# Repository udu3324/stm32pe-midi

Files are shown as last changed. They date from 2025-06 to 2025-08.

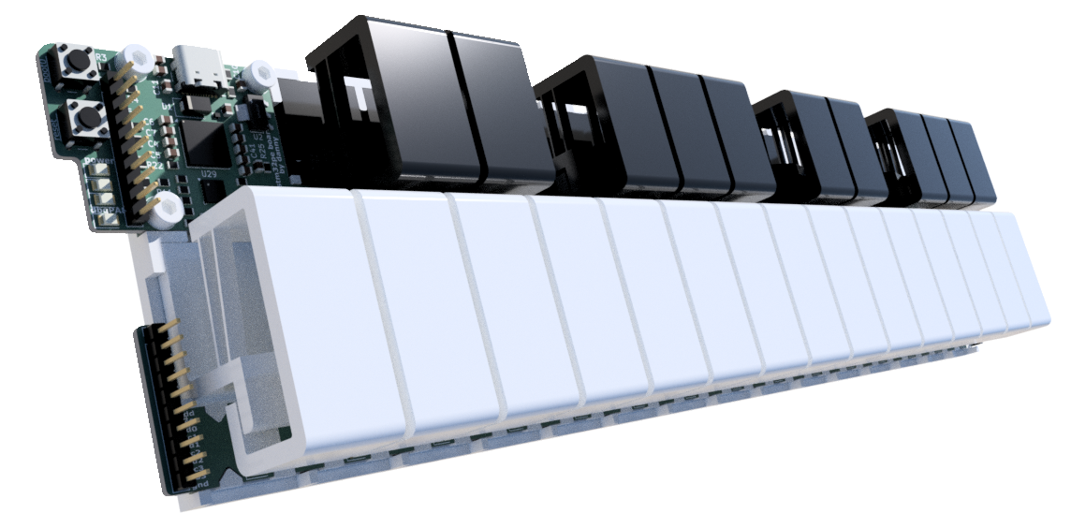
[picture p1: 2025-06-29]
cad/stm32pe-midi case v42 clear.png

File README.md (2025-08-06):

# stm32pe-midi controller



An expressive midi controller based on the stm32 ecosystem. It uses the MPE midi protocol to pass through signals that act as gestures/effects including velocity/note to any music DAW. (like ableton)

 - Uses the powerful STM32H7
 - Uses USB-C OTG to connect to a device
 - Has per key PWM leds for indication
 - Low profile/one sided pcb design
 - Small key footprint for compactness
 - Two octaves + extra key before an octave

See it in action [here](https://www.youtube.com/watch?v=022ZFJn4nkc)!

# Why I Made It

This controller will be able to make music more accessible by being more affordable to the typical person. Most MPE midi controllers on the market cost between [$500 USD to $2000](https://www.expressivee.com/2-osmose). I also made this project to touch the stm32 ecosystem and learn how to integrate and use it. This midi keyboard could also make my workflow nicer for making music in Ableton.



# Design

To reduce the cost of production, I decided to design a compliant mechanism (flexure) that would be only one part. It would reduce the labor and cost by a lot. This is because most keyboards/pianos have between 10 to 100 which I have reduced to a minimum of 2. A hall effect sensor is used to measure the position and rotation of a magnet embedded in each key.



# Problems

There were many problems while prototyping and laying out things. I had bare knowledge of how flexures worked and had to create as many prototypes as needed until the right movement was made. I also didn't know that the size of the board would be a big constraint that was completely ignored.

**I highly recommend to look over these issues before building another stm32pe device!!!**
A lot of tolerances for the 3d prints are based on my 3d-printer. Make sure to print segments before making the entire thing to test for fit between the pcb, magnet, and everything.

Problems during fabrication
 * TMAG5273 has a fixed i2c address which only differs by buying different models (B1, C1, D1) or by running extra interrupt traces
 * M screw spacers broke off when screwing into plastic
 * Too high of a tolerance between the board and 3d printed parts, had to cut off bottom two aligners on all keys
 * Connection (led mux) from main-board to other board was made through really tiny & painful to solder wires

Here's a list of problems after fabrication + firmware
 * The Black key flexure design suffers too much with plastic deformation permanently, as well as temporarily
 * ^ This issue also causes a permanent distance change with less distance to measure and use
 * TMAG5273 library has no calibration feature and the measured angle is offset when brought closer
 * Keys are a bit too slippery and need a dimple to grip the finger
 * Flexures on both key types are a little on the firm side, takes a little time to get used to
 * Last white key (b) is impractical as header wires are blocking its roll to pitch change up
 * The power on led is a bit too bright, not changeable
 * The base/case of the stm32h7 is kinda slippery
 * PLA flexures can get deformed under heat in a car which can leave a permanent loss of height on keys or mess more with the already high tolerance to allow press fitting

These issues do not make the stm32pe midi keyboard worthless or horrible to use, but are just little tiny problems that could be polished in the future.

# Firmware

 * [tinyusb lib](https://github.com/hathach/tinyusb) on MIT license
 * [i2c-mux stm32 lib](https://github.com/jtainer/i2c-mux) on BSD-2-Clause license
 * [stm32 tmag5273 lib](https://github.com/devOramaMan/stm32_TMAG5273) on No license (added a i2c address rewrite based on the datasheet as well as a crucial fix)

Thank you to all the open source libraries above to make this project possible. I don't think I would have the expertise to implement all my ics this well.

The firmware for the stm32pe midi controller is written in c/cpp on stm32cubeide and flashed with stm32cubeprogrammer. Amazing platform. Outdated UI (lol). **To be as transparent as possible**, some of the firmware was written/assisted with AI. About 20% of it was written mostly with AI, while the rest + logic that ties everything together was me. `mpe.c`, 80% of `helper.c`, 60% of `tlc5940.c`, and 5% of `main.c` with some fixes to `TMAG5273.c` was assisted with AI. I do understand what the firmware does. Depending on your perspective on AI, it shouldn't really matter as I know what I'm doing. 

All of the code is stored in `firmware/stm32pe_midi/Core/Src` or `/Core/Inc`. `Src/main.c` contains some user preferences that can be set through variables.

```c
//midi
int start_octave = 4; //midi code shift
int mt_send_black = 40; //midi on threshold
int mt_send_white = 30; //midi on threshold

//mpe
int16_t pitch_mpe_st = 682; //mpe semitone pitch range (682 = 4st, 341 = 2st)
float angle_mpe_padding = 15; //mpe pitch
float angle_mpe_realistic_max = 25; //mpe pitch

float aftertouch_mpe_white_padding = 9; //mpe aftertouch
float aftertouch_mpe_black_padding = 15; //mpe aftertouch

//octave
uint32_t octave_change_mode_time_threshold = 200; //diff change between mode/octive
uint32_t octave_led_flash = 500; //ms between led flash during mode

//led
int startup_cutoff_wait = 100; //led cutoff + cutoff for initial sensor readings saving

//mode
uint32_t octave_mode_hold_down = 1500; //octave mode keys milliseconds to hold down & change
uint32_t mpe_mode_hold_down = 3000; //~ same above but for mpe mode keys

//debug
bool disable_comport = false; //silences comport to possibly make processing faster?
```

# Wiring





# BOM
This is an approximate bill of materials that is a little flexible. It would be around $333.27, ±5 dollars in case of shipping or extra taxes/fees. Thank you Hack Club - Highway for funding this.

| Part | Cost | Count | Supplier | Note | Link |
|---|---|---|---|---|---|
| PLA Filament (white) | $16.99 | 1 | Amazon | I have a 3d printer and would like to print most of the parts. | [https://www.amazon.com/dp/B07PGZNM34](https://www.amazon.com/dp/B07PGZNM34) |
| PLA Filament (black) | $16.99 | 1 | Amazon | ~ (for the black keys) | [https://www.amazon.com/dp/B07PGY2JP1](https://www.amazon.com/dp/B07PGY2JP1) |
| UV Plastic Glue | $14.15 | 1 | Amazon | This is for the underside of the keys to stop scraping. | [https://www.amazon.com/dp/B00QU5M4VW](https://www.amazon.com/dp/B00QU5M4VW) |
| Header 10 Pins | $0.78 | 2 | DigiKey  | (does not include shipping/taxes) | [68000-110HLF](https://www.digikey.com/en/products/detail/amphenol-cs-fci/68000-110HLF/1878503) |
| Header 5 Pins | $0.63 | 1 | DigiKey  | ~ | [68000-105HLF](https://www.digikey.com/en/products/detail/amphenol-cs-fci/68000-105HLF/2023304) |
| PCB Fabrication + Assembly | $151.09 | 2 | JLCPCB | *no coupons applied yet | |
| PCB Shipping | $33.52 | n/a | ~ | | |
| Customs duties & taxes | $83.10 | n/a | ~ | | |
| Sales Tax | $15.24 | n/a | ~ | | |
| TOTAL | $333.27 | | | | |

I forgot to add two more parts to the bom. They have been covered out of pocket which is fine

| Part | Cost | Count | Supplier | Note | Link |
|---|---|---|---|---|---|
| 5mm Cube Magnets | $16.99  | 45 | Amazon | I could not find any listings with lower quantities | [https://www.amazon.com/dp/B0CW9GVTX2](https://www.amazon.com/dp/B0CW9GVTX2) |
| M3 5mm Screws | ¥2.14 | 50 | Taobao | Pretty cheap! (30 cents usd) | [https://detail.tmall.com/item.htm?id=722759297726](https://detail.tmall.com/item.htm?id=722759297726) |
| Female 10pin Headers  | $5.62 | 1 | Mouser | This is for the main board. The part itself **costs $0.63 without taxes/shipping.** | [https://www.mouser.com/ProductDetail/710-61301011821](https://www.mouser.com/ProductDetail/710-61301011821) |
| JLCPCB Two Design Fee | $38.99  | n/a | JLCPCB | 😭 i did not think about this while designing, i tried negotiating and doing everything | |
| TMAG5273-B1/C1/D1 | $23.28  | 18 | Mouser | i stg the datasheet said the sensor's i2c addresses were reprogrammable.. but they didn't say i needed to hookup interrupts to them too... lesson learned :p | |
| Total out of pocket | $85.18  | | | | |
| REAL TOTAL | $418.45 | | | | |

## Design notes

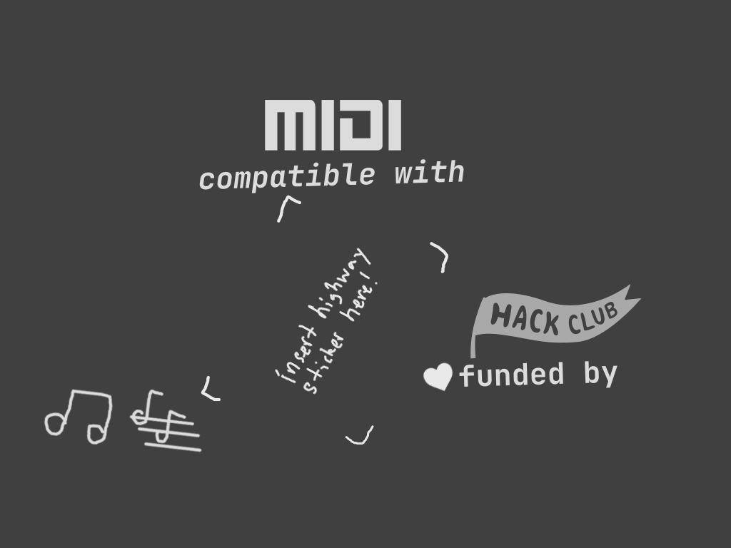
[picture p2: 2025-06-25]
pcb/stm32pe_midi/main_board_v2_graphic.png

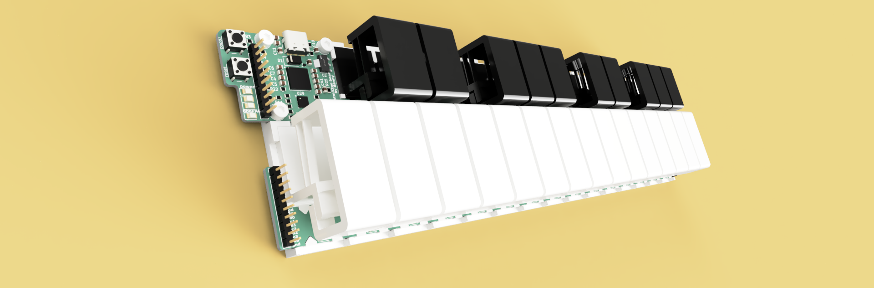
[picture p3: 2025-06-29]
cad/stm32pe-midi_case_2025-Jun-29_01-04-10AM-000_CustomizedView29163511781_png.png

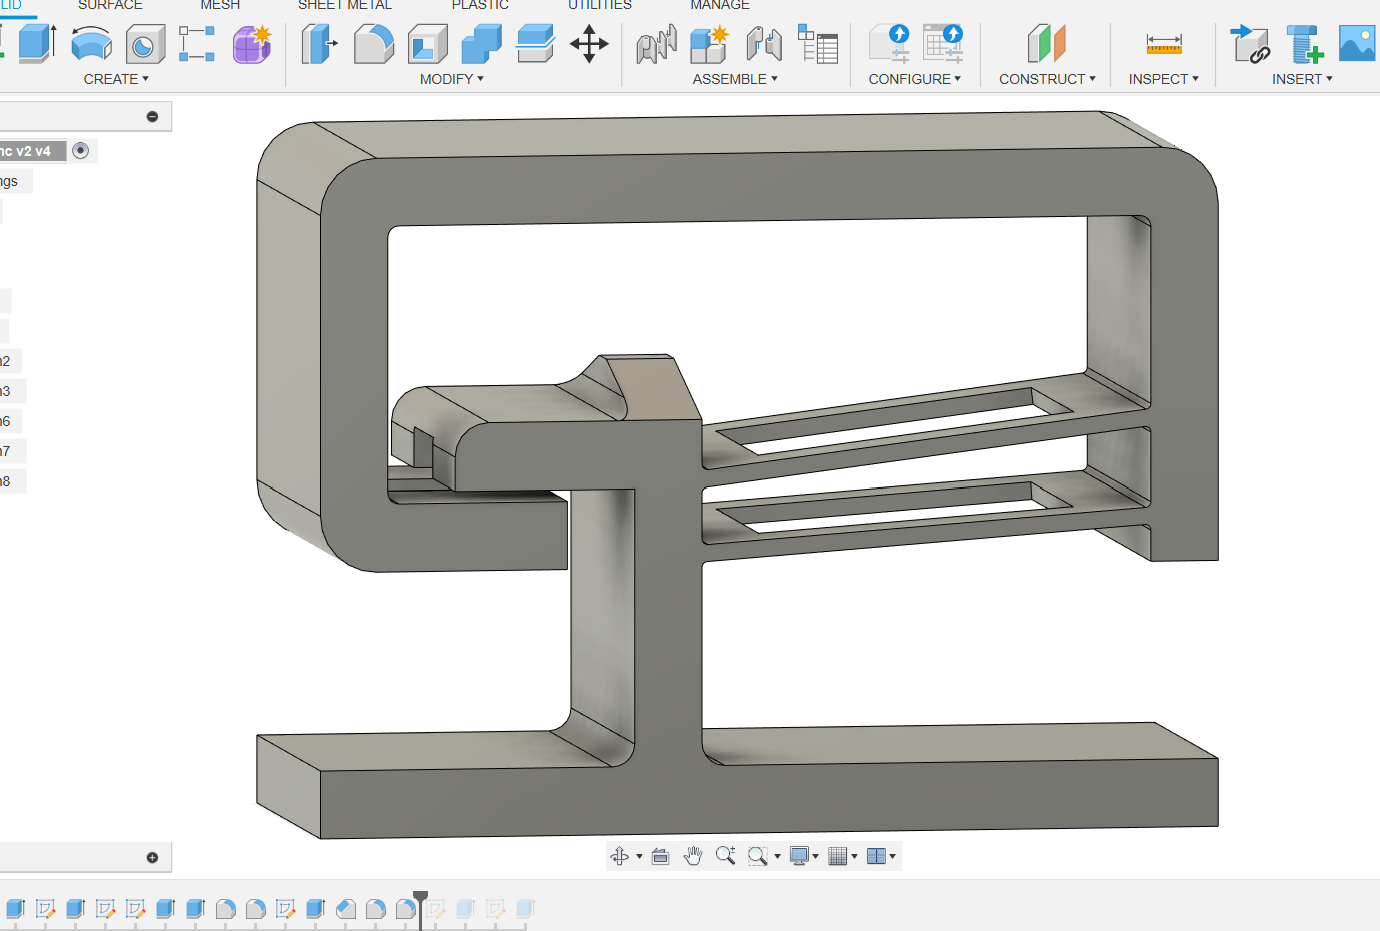
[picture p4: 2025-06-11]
cad/key/v2.png

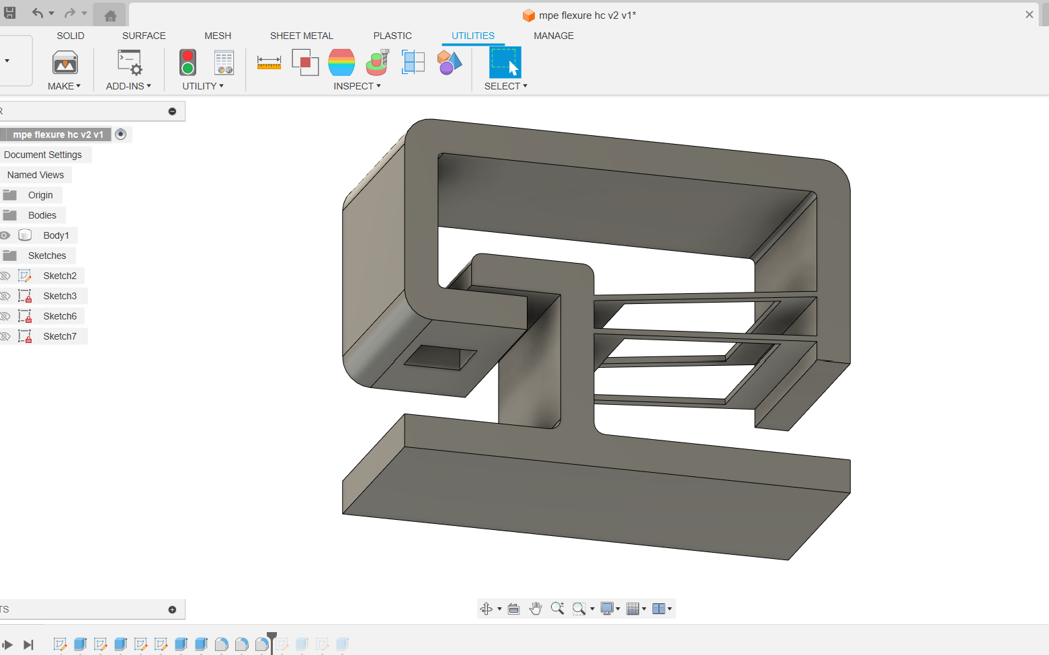
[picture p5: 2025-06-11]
cad/key/v1.png

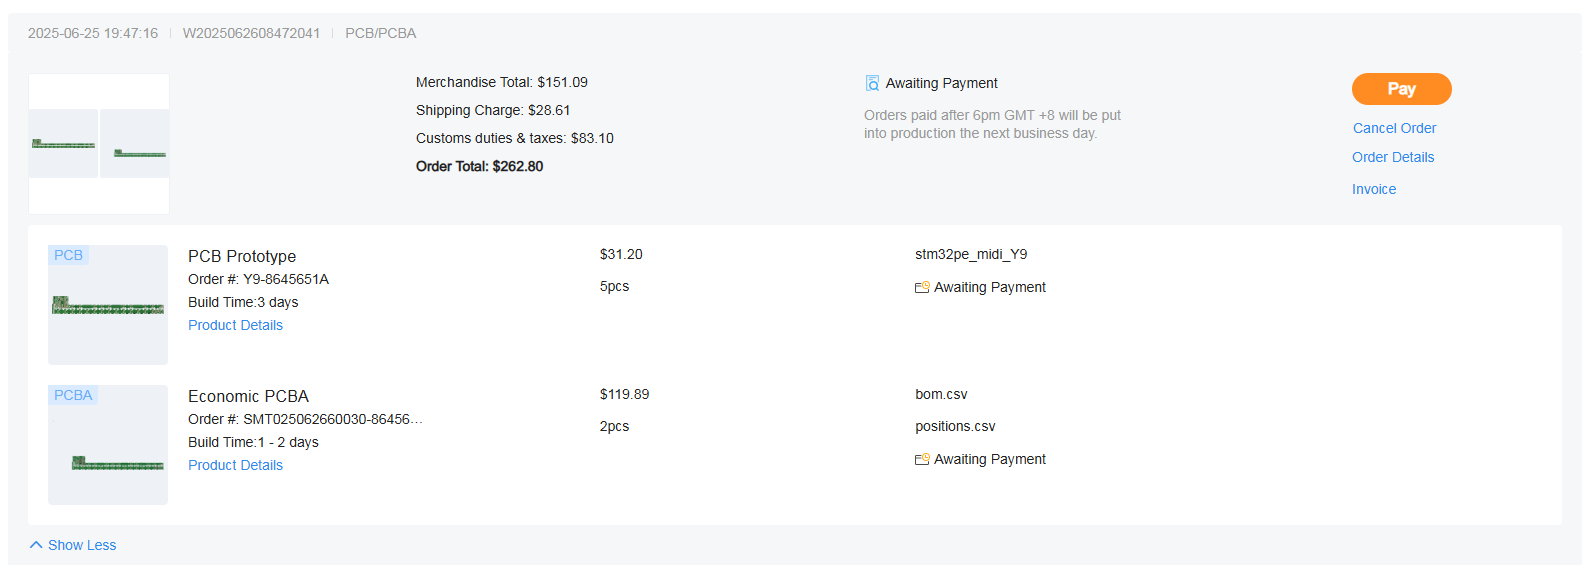
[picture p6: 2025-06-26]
production/jlcpcb info/cart.png

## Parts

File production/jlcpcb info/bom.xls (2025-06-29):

Comment | Designator | Footprint | JLCPCB Part #
LED_Small | D3,D33,D4,D5,D10,D11,D12,D13,D14,D15,D16,D17,D18,D19,D20,D21,D22,D23,D24,D25,D26,D27,D28,D29,D30,D6,D7,D8,D9 | 1206 | C3646938
SS14 | D1 | D_SMA | C2480
1μF | C13,C14,C8 | 0805 | C28323
LM3940IMPX-3.3/NOPB | U2 | SOT-223-4_L6.5-W3.5-P2.30-LS7.0-BR | C544820
4.7μF | C3,C5 | 0805 | C1779
2.2μF | C1,C2 | 0805 | C377773
100nF | C15,C16,C17,C18,C19,C20,C21,C22,C23,C24,C25,C26,C27,C28,C29,C30,C31,C32,C33,C34,C35,C36,C37,C38,C39,C40,C41,C12,C4,C6,C7,C9 | 0805 | C49678
TLC5940PWP | U30,U31 | HTSSOP-28-1EP_4.4x9.7mm_P0.65mm_EP3.4x9.5mm_Mask2.4x6.17mm_ThermalVias | C181653
0.47μF | C11 | 0805 | C13967
2.2kΩ | R10,R11,R12,R13,R14,R15,R16,R17,R18,R19,R20,R21,R22,R23,R8,R9 | 0805 | C17520
TMAG5273 | U10,U11,U12,U13,U14,U15,U16,U17,U18,U19,U20,U21,U22,U23,U24,U25,U26,U27,U3,U4,U5,U6,U7,U8,U9 | SOT-23-6_L2.9-W1.6-P0.95-LS2.8-BR | C3716049
10kΩ | R3,R4 | 0805 | C17414
330Ω | R27,R5,R6,R7 | 0805 | C17630
TPD2EUSB30 | U28 | Texas_DRT-3 | C2844720
33μF | C10 | 0805 | C342635
STM32H743VIHx | U1 | TFBGA-100_8x8mm_Layout10x10_P0.8mm | C964146
5.1kΩ | R1,R2,R24,R25 | 0805 | C27834
TCA9548A | U29 | Texas_RGE0024C_VQFN-24-1EP_4x4mm_P0.5mm_EP2.1x2.1mm | C555456
USB4105 | J1 | USB_C_Receptacle_GCT_USB4105-xx-A_16P_TopMnt_Horizontal | C3025063

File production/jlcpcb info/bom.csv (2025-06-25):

Designator | Footprint | Quantity | Value | LCSC Part #
C1, C2 | 0805 | 2 | 2.2μF
C10 | 0805 | 1 | 33μF
C11 | 0805 | 1 | 0.47μF
C12, C4, C6, C7, C9 | 0805 | 5 | 100nF
C13, C14, C8 | 0805 | 3 | 1μF
C15, C16, C17, C18, C19, C20, C21, C22, C23, C24, C25, C26, C27, C28, C29, C30, C31, C32, C33, C34, C35, C36, C37, C38, C39, C40, C41 | 0805 | 27 | 0.1μF
C3, C5 | 0805 | 2 | 4.7μF
D1 | D_SMA | 1 | SS14
D10, D11, D12, D13, D14, D15, D16, D17, D18, D19, D20, D21, D22, D23, D24, D25, D26, D27, D28, D29, D30, D6, D7, D8, D9 | 1206 | 25 | LED_Small
D3, D33, D4, D5 | 1206 | 4 | LED
J1 | USB_C_Receptacle_GCT_USB4105-xx-A_16P_TopMnt_Horizontal | 1 | USB4105
J3 | PinHeader_1x05_P2.54mm_Vertical | 1 | Conn_01x05_Pin
J4 | PinHeader_1x10_P2.54mm_Vertical | 1 | Conn_01x10_Pin
J5 | PinHeader_1x10_P2.54mm_Vertical | 1 | Conn_01x10_Socket
J6 | custom_pads | 1 | Conn_01x05_Pin
MOUSE-BITE-2MM-SLOT-1, MOUSE-BITE-2MM-SLOT-2, MOUSE-BITE-2MM-SLOT-3, MOUSE-BITE-2MM-SLOT-4, MOUSE-BITE-2MM-SLOT-5 | mouse-bite-2mm-slot | 5 | VAL**
R1, R2, R24, R25 | 0805 | 4 | 5.1kΩ
R10, R11, R12, R13, R14, R15, R16, R17, R18, R19, R20, R21, R22, R23, R8, R9 | 0805 | 16 | 2.2kΩ
R27, R5, R6, R7 | 0805 | 4 | 330Ω
R3, R4 | 0805 | 2 | 10kΩ
SW1, SW2 | SW_PUSH_6mm | 2 | SW_SPST
U1 | TFBGA-100_8x8mm_Layout10x10_P0.8mm | 1 | STM32H743VIHx
U10, U11, U12, U13, U14, U15, U16, U17, U18, U19, U20, U21, U22, U23, U24, U25, U26, U27, U3, U4, U5, U6, U7, U8, U9 | SOT-23-6_L2.9-W1.6-P0.95-LS2.8-BR | 25 | TMAG5273 | C3716049
U2 | SOT-223-4_L6.5-W3.5-P2.30-LS7.0-BR | 1 | LM3940IMPX-3.3/NOPB | C544820
U28 | Texas_DRT-3 | 1 | TPD2EUSB30
U29 | Texas_RGE0024C_VQFN-24-1EP_4x4mm_P0.5mm_EP2.1x2.1mm | 1 | TCA9548A
U30, U31 | HTSSOP-28-1EP_4.4x9.7mm_P0.65mm_EP3.4x9.5mm_Mask2.4x6.17mm_ThermalVias | 2 | TLC5940PWP

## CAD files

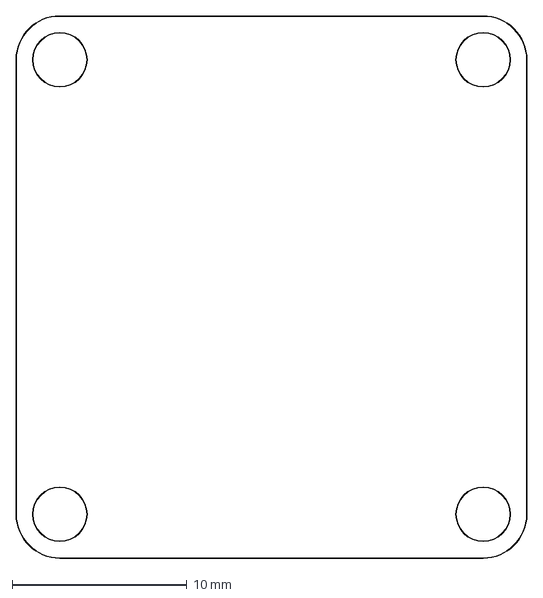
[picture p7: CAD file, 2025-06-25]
pcb/stm32pe_midi/main_board.dxf
29.2 x 31.0 mm

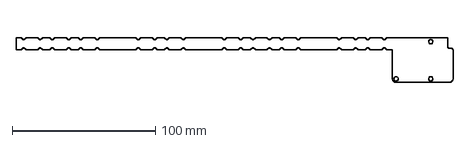
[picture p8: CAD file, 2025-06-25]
pcb/stm32pe_midi/main_board_v2.dxf
304.7 x 31.4 mm

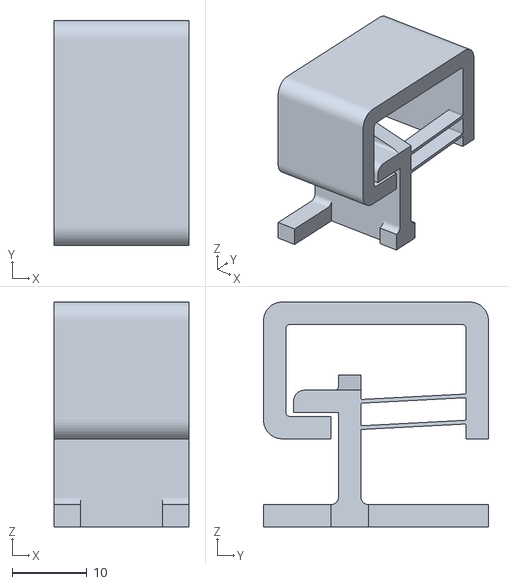
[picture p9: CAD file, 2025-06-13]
cad/small key/14.stl
18.0 x 30.0 x 30.0

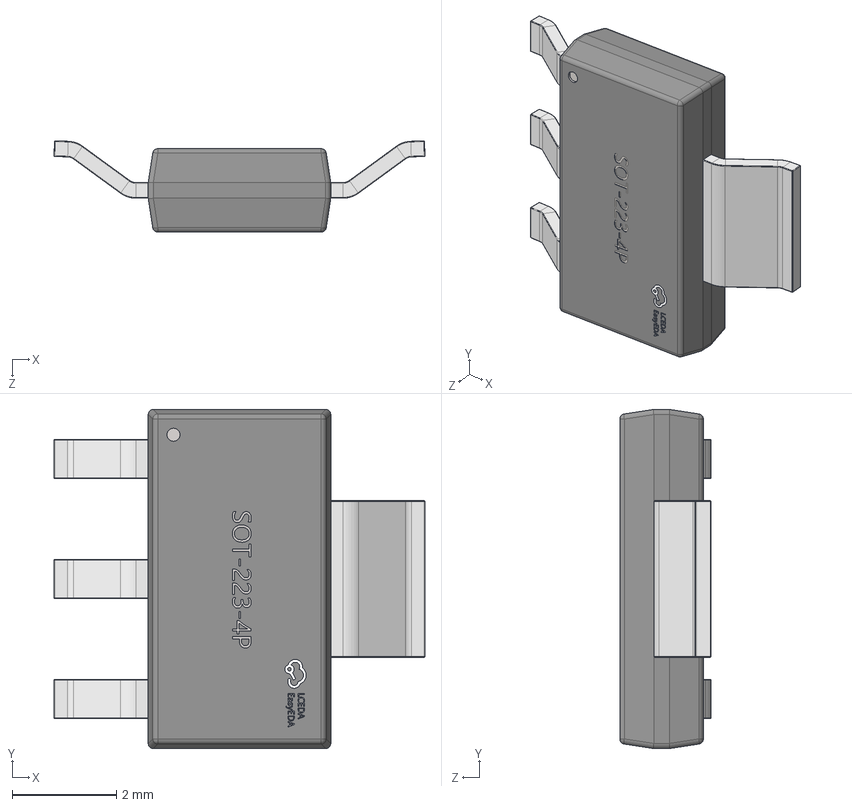
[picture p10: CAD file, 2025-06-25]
pcb/stm32pe_midi/SOT-223-4P_L6.5-W3.5-H1.6-LS7.0-P2.30.step
7.11 x 6.50 x 1.75 mm

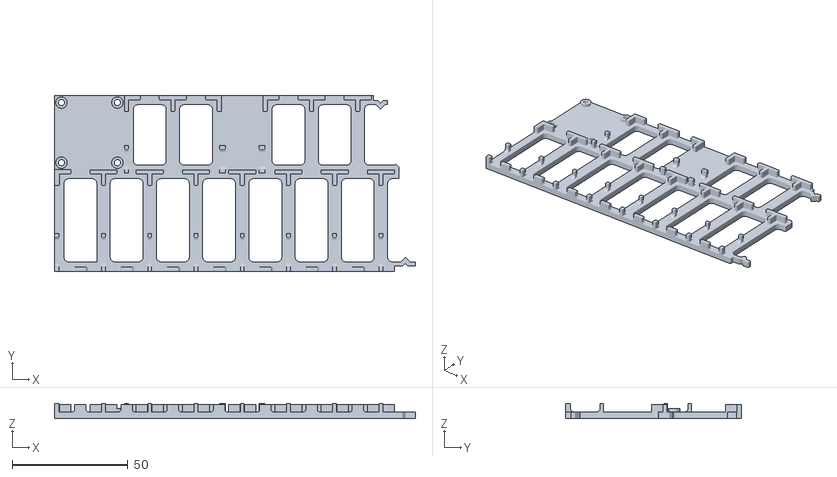
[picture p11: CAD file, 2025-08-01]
production/Case L.stl
156.1 x 76.0 x 6.50

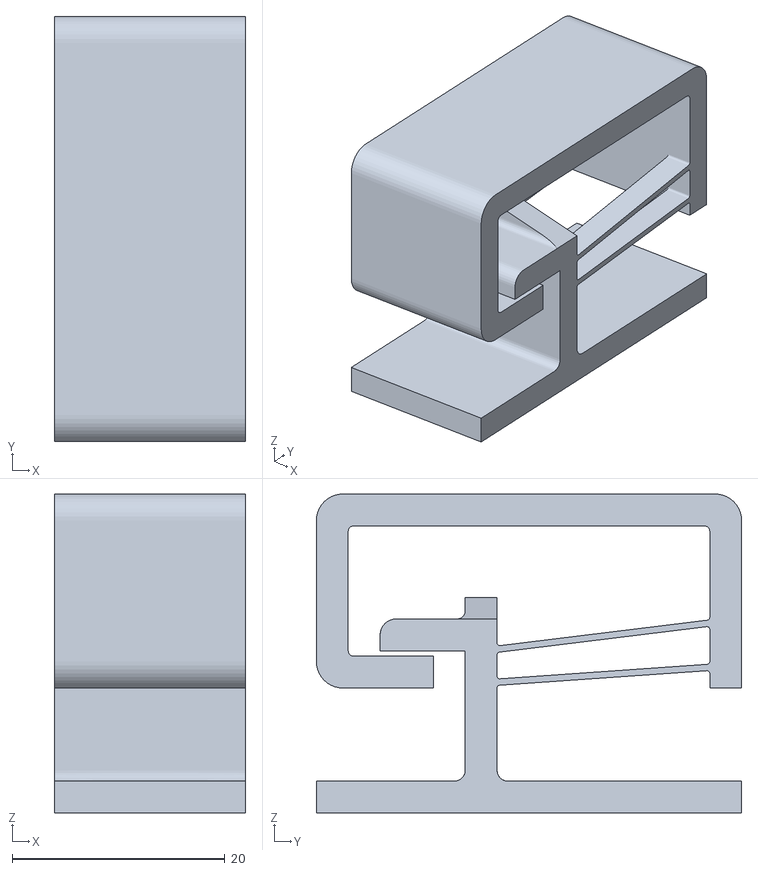
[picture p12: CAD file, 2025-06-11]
cad/key/v3.stl
18.0 x 40.0 x 30.0

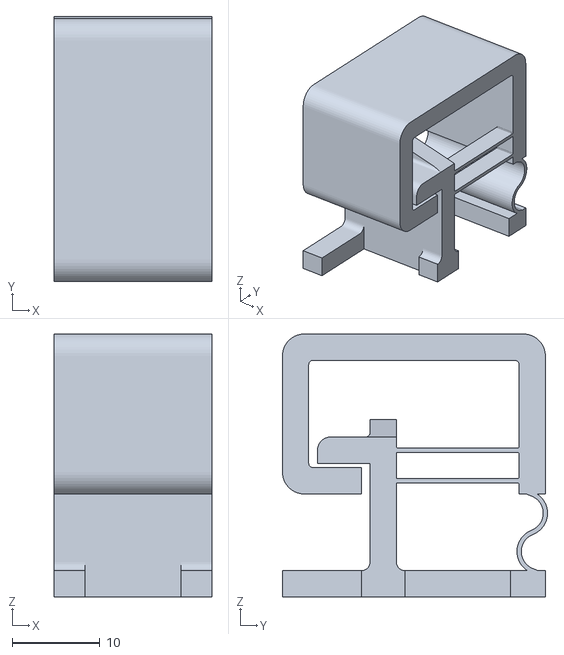
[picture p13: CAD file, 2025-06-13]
cad/small key/15.stl
18.0 x 30.2 x 30.0

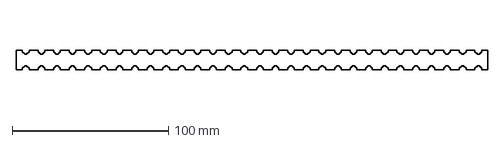
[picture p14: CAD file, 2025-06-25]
pcb/stm32pe_midi/sensor_line_1.dxf
302.0 x 12.7 mm

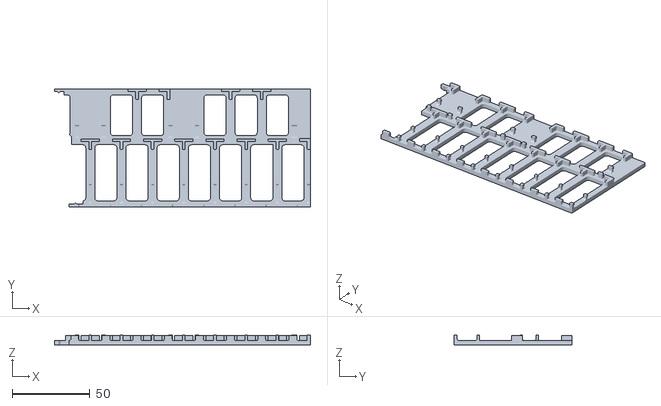
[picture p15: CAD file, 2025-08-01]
production/Case R.stl
164.2 x 76.0 x 6.50

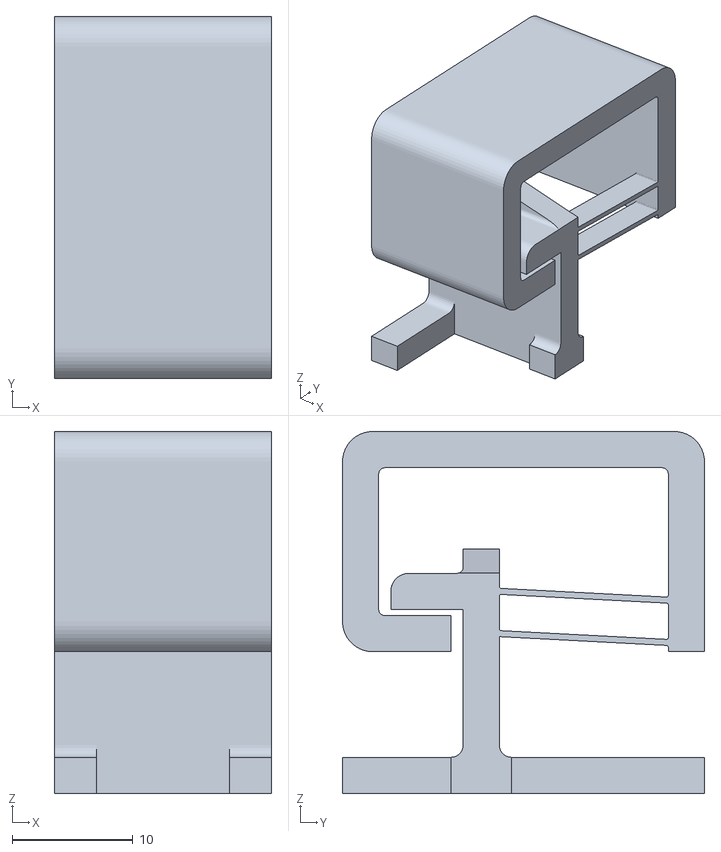
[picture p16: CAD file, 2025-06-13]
cad/small key/v11.stl
18.0 x 30.0 x 30.0

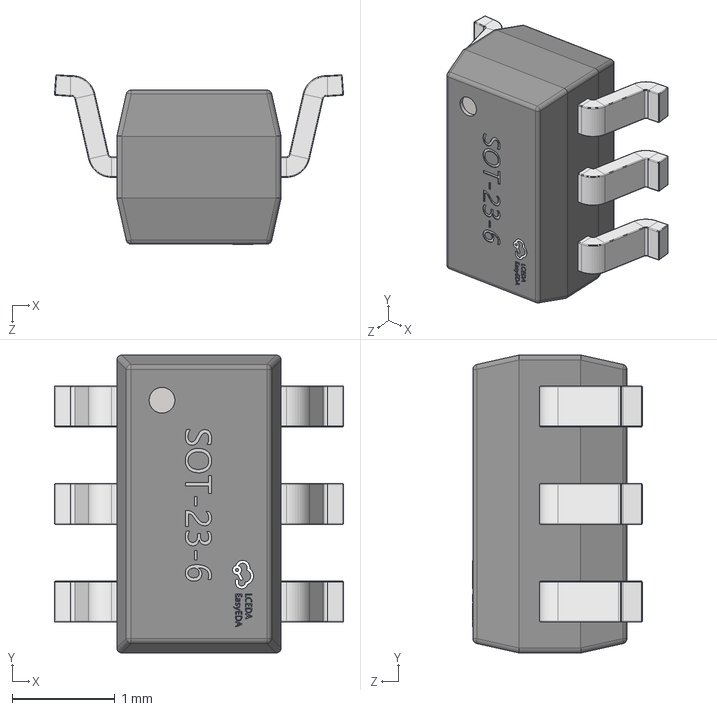
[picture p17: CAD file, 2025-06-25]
pcb/stm32pe_midi/SOT-23-6_L2.9-W1.6-H1.5-LS2.8-P0.95.step
2.81 x 2.90 x 1.65 mm

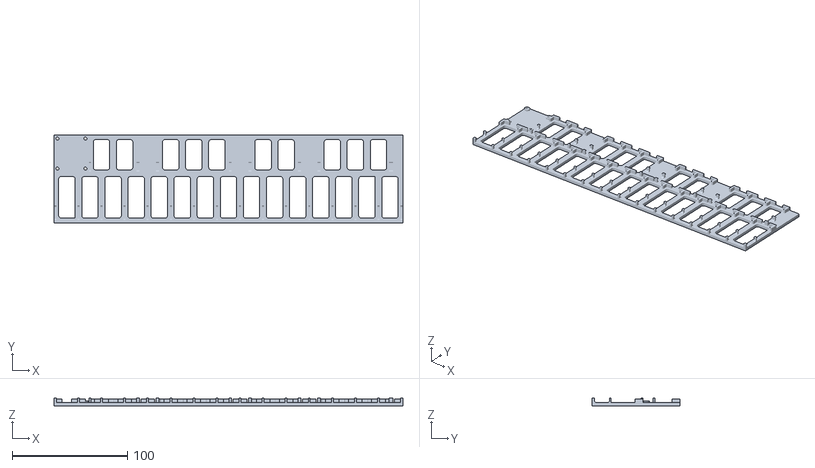
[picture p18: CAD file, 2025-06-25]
production/case.stl
302.5 x 76.0 x 6.50

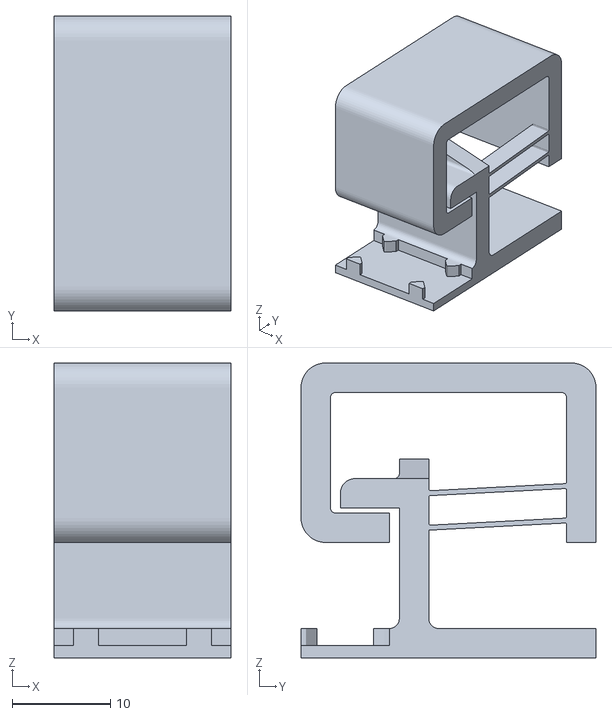
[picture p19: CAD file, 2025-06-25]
production/mpe flexure small.stl
18.0 x 30.0 x 30.0

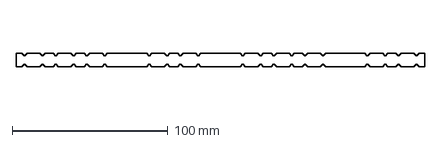
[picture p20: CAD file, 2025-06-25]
pcb/stm32pe_midi/sensor_line_2.dxf
262.0 x 8.70 mm

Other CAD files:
production/hc_flexure_key_magdim_good.stl
cad/small key/13.stl
production/mpe flexure.stl
cad/small key/12.stl
cad/key/v1.f3d
cad/key/v1.stl
cad/key/v2.f3d
cad/key/v2.stl
cad/key/v3.f3d
cad/small key/16.stl
cad/small key/smal ver v1.stl
cad/small key/small ver v1.f3d
cad/small key/small ver v2 final prototype v2.f3d
cad/small key/small ver v2 v16.f3d
cad/small key/small ver v2.f3d
cad/small key/small ver v2.stl
cad/small key/small ver v3.f3d
cad/small key/small ver v3.stl
cad/small key/v10.stl
cad/small key/v9.stl
pcb/stm32pe_midi/sensor_line_v2.dxf

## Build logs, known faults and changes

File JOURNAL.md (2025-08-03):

---
title: "stm32pe midi controller"
author: "@Danny"
description: "An affordable music keyboard that enables more expression through the MIDI Polyphonic Expression (MPE) protocol."
created_at: "2025-06-06"
---

**Total time taken: 52 hours**

**Total time taken: 131.5 hours (fabrication + firmware)**

# June 6th: Sketching out the idea

Today, I started researching the components that I would depend on. (stm32 ecosystem, i2c multiplexers, sensors) I then created some technical sketches of the device and drew some core concepts. 

Feature Set
 - Recognizable by Ableton (or any general DAW software)
 - Sends mpe midi (duh)
 - USB-C connection for flashing & otg device
 - (optional) 3.5mm jack for int. synth engine
 - Cool rgb indicators



Components Needed
 - **STM32H7**43VIH (great mcu, bga style needing multilayer pcb fab)
 - TMAG5273 - I2C hall effect sensor
 - TCA9548A - For multiplexing i2c connections
 - Possibly SDRAM for an internal synth engine
 - IO Ports, Encoder
 - other smd components

**Total time spent: ~3 hours**

# June 8th: Getting the TMAG5273 to work

The core idea of this controller was to use a hall effect sensor (tmag5273) to measure the position of a magnet and output many things out of it. Before continuing any further, I need to make sure that it works.

## Wiring

Two resources were used in wiring the sensor. I looked at the [datasheet](https://www.ti.com/lit/ds/symlink/tmag5273.pdf) first to get an idea of the pinout and reference circuit, as well as how sparkfun implemented it through their board [here](https://docs.sparkfun.com/SparkFun_Qwiic_Hall_Effect_Sensor_TMAG5273/assets/board_files/schematic-mini.pdf). 

I decided for now to use my [esp32 devkit](https://docs.espressif.com/projects/esp-dev-kits/en/latest/esp32s3/esp32-s3-devkitc-1) to test out the sensor before switching to the stm32 ecosystem.

The INT pin for disabling the sensor was left unconnected, SDA and SCL to any GPIO with a 4.7k pullup resistor, and VCC to 3.3V. 



## Code

I am using PlatformIO's VSC plugin to flash and test everything. The first thing to flash was a simple [I2C device scanner](https://randomnerdtutorials.com/esp32-i2c-communication-arduino-ide) to see if I had everything wired correctly. This process took quite long as I did not know if the sensor was fried or if my wiring was horrible. (it was both 😭)

I can then move onto [sparkfun's library](https://github.com/sparkfun/SparkFun_TMAG5273_Arduino_Library) to communicate with the tmag sensor.

```cpp
#include <Arduino.h>
#include <Wire.h>
#include "SparkFun_TMAG5273_Arduino_Library.h" 

TMAG5273 sensor;

uint8_t i2cAddress = 0x35;

const int ledPin = 17;  // GPIO 17
const int I2C_SDA = 4;
const int I2C_SCL = 5;

void setup() {
  Serial.begin(115200);
  delay(1000);
  pinMode(ledPin, OUTPUT);  // Set GPIO 17 as an output
  Wire.begin(I2C_SDA, I2C_SCL);

  Serial.println("hello world");

  // If begin is successful (0), then start example
  if (sensor.begin(i2cAddress, Wire) == 1) {
    Serial.println("Begin");
  } else {
    Serial.println("Device failed to setup - Freezing code.");
  }
}

void loop() {
  // Checks if mag channels are on - turns on in setup
  if (sensor.getMagneticChannel() != 0) {
    sensor.setTemperatureEn(true);

    float magX = sensor.getXData();
    float magY = sensor.getYData();
    float magZ = sensor.getZData();
    float temp = sensor.getTemp();

    //Serial.printf("( %7.2f, %7.2f, %7.2f ) mT   %6.2f C\n", magX, magY, magZ, temp);
    
    Serial.printf("%f,%f,%f,%f\n", magX, magY, magZ, temp);
    //relative to dot on ic facing forward to viewer
    // left-right, forward-backward, up-down
  } else {
    Serial.println("Mag Channels disabled, stopping..");
  }

  delay(50);
}
```



**Total time spent: 3.5 hours**

# June 9th: Designing the flexures for the keys

I started off on a new page and drew two concepts of how I could implement [flexures](https://web.mit.edu/mact/www/Blog/Flexures/FlexureIndex.html) in a key. It would allow me to build the device with less parts with the same functionality, as well as saving on money. The print layers also had to be thought of to make sure flexing won't compromise on durability and break. 

Below is some rough sketches of how the keys would look like and how it would come together with the pcb. 



**Total time spent: 2 hours**

# June 10th: Cadding and 3d printing key prototypes

I decided that I'll choose the more simpler key with only one model that i need to create. I am using Fusion 360 to accomplish this with their personal plan.

Key Requirements (ahaha get it)
 - Fits a 5mm cube neodymium magnet
 - Flexes easily, doesn't strain fingers
 - Can flex in all the neccesary axis
 - Use little to no extra plastic when printing

## Prototype V1

v1

This was the first prototype to kickstart my idea of a key. I started off with a side sketch and extruded it, then adding features in the other dimension. 



Well.. It did not turn out great the first try, and of course it would never be perfect the first try. I designed the flexure to be too thin and it wouldn't hold up the upper weight of the key. It also could not fit the magnet.

Instead of it flexing left or right, the key decided to rotate in place which i did not intend to. But wait... This gave me a new **game breaking** idea! Instead of+ designing it to move in two axises, I can just have it move in one axis and rotate in place which can also be measured by the sensor! It is something so unique that I could have never thought of without this prototype. 

## Protype V2

v2

This second prototype solved many problems of the first one. It finally held the magnet, its own weight, and almost has the rotation action perfect.



The only two problems now is that it is a bit stiff for a key on a midi keyboard as well as something I didn't think about for fabrication. Pressing it all the way down while trying to rotate it scrapes the layer lines making an irritating noise. 

## Prototype V3

v3

This prototype solved the issue of the key being too stiff. It requires less force to push down now, but still has the scraping problem which I'm not sure how to solve. I'll do that later lol.



The data isn't as smooth as i hoped, but I think thats an issue in the code. The white line looking like a sine wave is the rotation movement of the key.

**Total time spent: 5 hours** (2 hrs of printing)

# June 11-13th: Prototyping the smaller keys

I decided that there would be a smaller version of a key for the sharps and flats on the controller. It seemed easy at first until changing the length of a key would mean tweaking every other aspect of the flexure endlessly.



A total of 13 prototypes were printed. Many problems were faced, including but not limited to.... low durability, permanent deformation, too much pressure to push down, no springines, and my lack of knowledge in making flexures. Although I chose aesthetics over functionality, I think everything will turn out great. 

**Total time spent: 2.5 hours** (accumulated, not including hours of printing)

# June 16th: Creating board schematics

I started working on the schematics for the board to bring all the components I need together.



So far, I have been following the [power supply scheme](https://www.st.com/resource/en/datasheet/stm32h743vi.pdf) from the stm32 datasheet as well as researching some other sources. I chose KiCad to build my board in as it is free and an amazing open source tool. 

I still need to add some sort of fuse to the VBUS of the usb-c to protect against esd, as well as my sensors, leds, possibly a dac with audio out, and most definitely a button to allow flashing firmware to the mcu. 

**Total time spent: 3 hours**

# June 17th: Adding the rest

The boot and reset button needed to flash firmware was added as well as some useful indicator LEDs.



I decided to create a sub-sheet to fit all my sensors on another page. 



**Total time spent: 3 hours**

# June 18th: Working on cad assembly

I decided that I would bring everything together to then model the size of the pcb to then take into KiCad. Currently, I am only familiar with OnShape's assembly feature and have no clue how it will go. 



It went horrible of course. I tried editing my sub-assemblies to add a pcb groove but kept on running into so many issues. It took many sketches and saving/syncing issues until I finally was able to modify parts across f3d projects without f**king everything up. 



I made sure to include a 0.15mm gap which would hopefully allow some tolerance for the pcb to fit. (±0.2mm for shape, ±10% for thickness) It would also create a friction fit for the board as well.

**Total time spent: 4 hours**

# June 20th: Adding leds + more



I had to multiplex my leds to use less io on the stm32. The TLC5940 seemed like the best fit for me as it was pwm and would be nice if each key would have some sort of power indicator. 

I also used KiCad's feature of assigning every symbol to a footprint. I decided on every capacitor and resistor having the same package size (0805/2012 metric) and it being not microscopic in case of any repairs and to simplify the bom.



I decided to add a way to output audio. It uses a MCP4922 and two LM396s to allow simple, not audiophile quality, audio delivery to the user.



I was able to test a more simplified/mono design of the audio circuit some time ago with the parts I got from high seas.

**Total time spent: 2 hours**

# June 22th: Cadding plate + pcb layout



I finished up the plate/thing that would hold everything together. So far, most things are press fit into place while the main board uses m3 screws.



I had no clue what i was getting myself into. Everything is laid out with the proper resistors or capacitors next to each other, but its a super dense board which creates a whole list of other challenges.

It was a pain trying to get everything to fit in the first place. I had to remove two extra leds, remove the entire audio output circuit (rip..), redo some schematics, and contemplate my life choices. 



All that's needed left is to route all the traces and place the pullup resistors for the sda/scl lines, as well as calculating the amount of headers i need for the wires between the three boards.

**Total time spent: 7 hours**

# June 23th + 24th: Unseen Constraints - Routing All Traces



I should have thought of the size of my board before doing anything. That was my hugest mistake. I was constrainted to the size/shape of my board which I never thought of while cadding only until now after some work was done.

I had to...

 - remove some features
 - resize the board to fit some components
 - constantly mess around with previous traces (because past me did not think about the future)
 - edit the heat spreader of the led multiplexer to be smaller which is kinda sus but who cares lol
 - cope



In the end, I managed to get everything wired up. KiCad still yells about certain things being unconnected as well as a list of other stuff that isnt really important. I'm really proud of the work as this is a new high for me.



While 80% done tracing everything, I decided to export the pcb to jlcpcb to see how much it would cost so far. It was priced around ~$140 USD for assembling two boards. I then clicked checkout and... I forgot there was tariffs going on right now.. (totaling around $230)

**Total time spent: ~14 hours**

# June 25th: Final touches + more

kicad_t1TWV0PZLa

After routing everything, I made sure i had no critical errors by using KiCad's design rule checker (DRC for short). It revealed a ton of problems like unconnected grounds, traces, and more. Although some components were marked as too close to others, it was only by a little and i could safely ignore it.





I have no clue how i didn't notice this at all. I placed my sensor in the wrong place and only found out last second. It wasn't a pain to move though.



Here's the actual final final look of the pcb. It is amazing.

**Total time spent: 3 hours**

# MILESTONE: MY PROJECT WAS SUBMITTED AND APPROVED HERE

This log is to just seperate my prep and building phase.

**Total time spent: 0 hours**

# July 7th: 3d-printing the Case



My 3d printer was a bit too small to actually print the entire case in one piece, so i instead designed a clip system to piece it together.



The first attempt was a bit too tight, so I used fusion 360's variable parameter features to easily change one number and retry.

**Total time spent: 2 hours**

# July 8th: Actually 3d printing the case and assembling it



It was perfect. I did some post processing to remove some strands as well as pla left behind by prusaslicer's ironing feature.

I used the uv glue to keep everything together permanently. I repurposed a old uv nail lamp to cure the glue.

**Total time spent: 3 hours**

# July 9th: The boards have arrived!



The boards needed some preprocessing as well as some components had to be hand soldered on.

I used a dremel to seperate the sensor board from the main board and tried my best not to breathe in any of the toxic fibers.

**Total time spent: 5 hours**

# July 10th: Soldering + 3d Printing More Stuff



The board needed to have some male/female headers soldered on as well as buttons too. That was the easy part. I now needed to solder header wires to extremely small/close together pads on the right side. I ended up ripping a pad off while doing this somehow. 😭 Good thing JLCPCB has a minimum two PCBA boards so I can start over.

I also printed most of the white keys and did some post processing of them. (removing some pla stuck to the sides of the print after the ironing stage)



I tried powering on the board but the power led was not on!!! There is no way i designed this to be nonfunctional. I whipped out my multimeter to see where voltage wasn't flowing, and saw that one of my safety capacitors for something was the main culprit.



I fucked up. I tried removing this with a soldering iron on my board thinking it would evenly melt both pads. It ripped one off. Good thing surface tension is a thing though, as it magically created a new pad for me and bridged them together.

# July 11th: Time to go to Undercity!!!

My project made me eligible to go to undercity!! It's my first time ever doing a hackathon so i am a bit nervous. 

**Total time spent: 0 hours**

# July 16th: Printing more stuff



I printed out the rest of my black keys. Nothing was done much today as i was still recovering from undercity lol.

**Total time spent: 30 minutes**

# July 17th: Fitting things together



My tolerances are... a bit too tight. In the picture above, you can see all of the white keys installed. They press fit together with the case, but do it too much. It caused the case to bend and overall make it a bit longer. This is horrible as there are also tolerances on the pcb which make it impossible to fit with an extra milimeter.

I managed to fix this by sanding down some of the keys that seem too big.

Also seen in the image above, some of the keys seem a little janky/bent. This is because I was postprocessing it and left it in a hot car.

**Note to self: DO NOT LEAVE 3D PRINTS IN A CAR ON A HOT SUMMER DAY**



I bought the wrong size magnets. (also they seem kind of less strong but its ok i think) They should press fit in but its too loose and i am forced to super glue each and every one of them. I should have only printed one to see if the fit was perfect for the magnets i bought instead of the magnets i had on hand.

**NOTE TO FUTURE SELF: print one thing at a time to see if it actually fits before printing/processing it all**

For some reason though, there was a press fit on the black keys but not white. This is really strange as i am pretty sure both have the same dimension cut out.

**Total time spent: 6 hours**

# July 18th: It's finally built!! + starting on firmware



The tolerances were so tight. I did not add them all up and did not leave enough wiggle room for myself. It all worked out in the end though, as for some reason, all my leds are on without any code to trigger them. Nice.



I am using a combination of STM32's programmer and cube ide to get things started. The UI for setting things up is really nice, but I am still getting used to the workflow. 

**Total time spent: 2 hours**

# July 20th: Learning the ways of STM32CubeIDE/CubeMX 

I have never coded c/cpp before, but do have java experience. It is a little different with c header files, but it all worked out okay in the end.



I was able to sucessfully implement my TLC5940 ics that multiplex all the LEDs for each keys. It was a pain as I really had no clue what i was doing, as well as the weird way i implemented them.



There are two ics connected together with both having a different amount of leds. It is such a weird implementation that took so much trial and error from both me and uhh.. ai.. to get to finally work. The most important helper function now is the premapped one which makes interaction with them extremely easy.

```c
void TLC5940_SetMappedLED(uint8_t logical_index, uint16_t brightness) {
	static const uint8_t mapping_table[10] = { 0, 1, 2, 3, 4, 5, 6, 7, 8, 9 };

	uint8_t physical_index;

	if (logical_index < 10) {
		physical_index = mapping_table[logical_index];
	} else if (logical_index >= 10 && logical_index <= 25) { // 10–25 to physical 16–31
		physical_index = logical_index + 6;
	} else {
		return;
	}

	TLC5940_SetLED(physical_index, brightness);
}
```

**Total time spent: 5 hours**

# July 21st: Initializing the TCA9548A

I found a good [library](https://github.com/jtainer/i2c-mux) from jtainer that can handle my multiplexer for my i2c devices. The only problem now that i need to change the addresses on my TMAG5273s as they are all the same.

**Total time spent: 2 hours**

# July 22nd: Getting the TMAG5273 to work

I found a neat little [library](https://github.com/devOramaMan/stm32_TMAG5273) from devOramaMan that implements the hall effect sensor to work with the stm32 hal.

I tried getting the y axis values and mapping it to my pwm leds, but of course, it did not work first try. I should have designed some sort of uart connection to my board but had to go with setting up a virtual com port device.



I had no clue what i was getting myself into. All these steps led me to this. It took so long troubleshooting why it didn't show up in my taskbar as a USB device. Turns out.. It shouldnt! It shows up only in device manager in a hidden dropdown that i didnt even know that existed.

**Total time spent: 6 hours**

# July 23rd: TMAG5273 Pain

I am now experiencing even more issues. Either I am not using the library correctly or i2c is running directly over the com port communications and interrupting anything from going through.

There is a bunch of troubleshooting I've done that has gotten me little steps closer. I just have no clue what to do.

Currently on this commit, everything just gives up and freezes on the `TMAG5273_Init(&tmag);` line. I am losing all my hairs.

**Total time spent: 7 hours**

# July 24th: A light from the dark



I have found a discord server dedicated to the stm32 ecosystem. I immediately wrote a forum post to them about my issue, being very informative as possible. A kind person gave me the best resource I've ever seen.

[stm32world.com](https://stm32world.com/wiki/Serial_Debugging)

Turns out, something was wrong with me casually writing to cdc everytime to send a debug message over. Instead, they have a nice cookie cutter function that replaces `printf()` to make my debugging actually work. A huge thanks to their community.

I can now focus on my original problem of getting my i2c sensor device to be recognized and parsed. (foreshadowing: it was painful)

**Total time spent: 2 hours**

# July 27th: Finally getting my hall effect sensors working



It took so much trial and error to get **one** sensor working. Turns out, the library I use had some problems with the device id. (in TMAG5273_ReadMagneticField) I don't have  much experience in i2c devices, and i also kind of have a deadline, so i resulted to using two AIs to help me solve this issue.

It took me about 15+ chats on chatgpt, 50+ lines of debugging, and a switch to Github Copilot to give better context. The final result was about 10 lines of code to fix the external library I found.

I can finally now move onto trying to rewrite the addresses of each tmag as they aren't unique and will cause i2c communication conficts.



I bought all of the A1 models which have all the same address. I read in the datasheet originally that they were editable so i thought it was fine, but i think it might be a bit hard. It also is a money saving technique i used as each model would count as an extended part, about 4+ usd for each model.

Why did Texas Instruments design their sensors like this? 

**Total time spent: 6 hours**

# July 28th: Working on midi protocol

I did further research and found out that I bricked my own board. I can't rewrite the tmag's address as it will be targeting all of the i2c devices of that same address, and will overwrite the ones that I don't want. Welp, that sucks.

I decided to work on the midi instead and implemented [TinyUSB](https://github.com/hathach/tinyusb) to help me turn it into a recognizable midi device.

This [github discussion](https://github.com/hathach/tinyusb/discussions/633) was a massive help in doing it, and it was pretty easy compared to writing my own custom device class implementation through [HAL](https://electronics.stackexchange.com/a/546927). Although, I should probably learn it the hard way for the future.



I finally got midi to be generated from my board!!! But.. It is inconsistant.



Turns out, the midi test function i used has a hal_delay which runs in the func > while loop > main.c which blocks all other things from running. It was fixed by using the HAL ticking function to avoid sleeping.

**Total time spent: 5 hours**

# July 29th: First functional key!!!



The triggering of a key was pretty easy. It was a different story for the velocity though. All i needed was to parse the sensor's distance and have cutoffs to trigger midi notes being on and off. For the velocity, It was the measurement in how much distance changed over time. A distance that occured in a shorter amount of time would have more velocity, while a longer time would have less velocity.



Recording the output midi worked perfectly, and I made sure the code could be scalable to the rest of the 24 keys.

**Total time spent: 3 hours**

# July 30th: SMD Soldering



So i bought a hotplate but it did not come with a charger brick for powering it with 20V 3A. I improvised by using my bench powersupply, usb-c breakout, and my phone charger cable to make it all work last second. (all of these came from hack club funding, tysm!!! well, not the cable)



I had to use my hot air gun as well as my hot plate to remove and replace my sensors. It was pretty easy removing them! It was the opposite for replacing them...



These ic chips are so small and I don't have any extras as they all cost about a dollar each. I dropped two and gave myself two heart attacks.

I used my tweezers to do everything. I do not own a solder paste stencil/syringe, just a tub of it. I had to shape the solder paste onto the sot-23 pads and it was horrible.

After soldering, I made sure everything was connected and nothing was bridged with a multimeter.

**Total time spent: 8 hours**

# July 31st: Getting all the keys to work



I went with the approach of getting all the i2c channels being combined together through my mux. This would be better than looping through all six of them which possibly could slow down my main loop.

To do this, I would have to give all my sensors unique addresses. This is because my fix from yesterday made all the sensors unique in one channel, but that channel's addresses are the same from the other channels.

The library i found for the TMAG5273 does not have a function to rewrite i2c addresses, so I had to make one somehow.

```c
uint8_t TMAG5273_RewriteI2CAddress(TMAG5273_Handle_t *pHandle, uint8_t new_addr) {
    if (new_addr < 0x08 || new_addr > 0x77)
        return 3;
    uint8_t reg_val = (new_addr << 1) | 0x01;
    uint8_t result = TMAG5273_WriteRegister(pHandle, 0x0C, reg_val);
    if (result == 0) {
        pHandle->address = new_addr; // update handle's address
    }
    return result;
}
```

I had some trouble using it at first, but turns out, I had to initialize the sensor, and then use it. bruh.



After getting the main loop working with all 25 sensors, it was magic. The lights were pwm controlled by how far the magnet was on each key. It was amazing.

I had to implement a value that would normal the resting sensor values as some would be too close to the sensor. It was some neat logic that works flawlessly.

**Total time spent: 5 hours**

# August 1st: Velocity and Octave Change





My original velocity sensing code was a bit finicky and wasn't actually measuring the time between two points. I updated it now to be more reliable and mapped to a realistic curve.

I noticed that there was some sort of latency with the sensors, so I edited the system clock speed in cubemx from 64 to 400. I didn't notice any change though.



Finally, I added a way to change the octave by holding two keys for 3 seconds to turn on octave mode. It took quite a while to add this feature in, but made the user experience so much better.

All the timing was based on `HAL_GetTick()` and was a little hard to think about. It was like pressing tap on a stopwatch and measuring that time from there. The last problem I had while trying to implement this mode was getting out of it. It would move an octave up or down as the keys used to get into octave mode were also reused to go up or down an octave. To fix this, I had to put a delay of 200ms to check if both keys were pressed.

**Total time spent: 4 hours**

# August 2nd: MPE Protocol Implementation + Finished!!! 

The MPE MIDI protocol is an extension of the regular midi protocol, so it was quite easy to convert a midi device to a mpe midi device. I created `mpe.c` to have all the mpe based functions all in one place. The only difference was that every note had its own channel and there was a bit more logic to make that happen. Those channels can then be sent extra data like aftertouch and per key pitch change.



```
if (angle.angle < 91 && angle.angle > 44) { // 44-91 down
	shift = map_float_to_int16(angle.angle, 44, 91, -4096, 0);
} else if (angle.angle > 100 && angle.angle < 134) { // 100-134 up
	shift = map_float_to_int16(angle.angle, 100, 134, 0, 4096);
} else if (angle.angle < 44) { //under 44
	shift = map_float_to_int16(angle.angle, 36, 44, -8192, -4096);
} else if (angle.angle > 134) { //over 134
	shift = map_float_to_int16(angle.angle, 134, 155, 4096, 8192);
}
```
At first, most of my pitch change calculations were relatively based on an arbitrary angle that isn't shared by all of the hall effect sensors. This would cause some keys to have a bias to be pitched more up or down than usual. I solved this by storing the keys first angle from its first actuation. 

The only caveaut to this is that the user may not press the key flat at first which create a bad reference for later calculations.



After finally setting up a ton logic that would make the per key pitch feel more intuitive, it felt like magic. It felt so surreal that I was making music as expressive as this.

Aftertouch was then added as it was pretty easy to do. A ton of calculations for the pitch, velocity, and aftertouch also depended on if the key was white or black as the flexures acted differently.

I still cant believe I actually made this. Its like in the Roli and Expressive E commercials. I managed to make my first midi controller that works well enough with capabilities of controllers costing upwards of $2k.

Thank you Hack Club for funding this.

**Total time spent: 8 hours**

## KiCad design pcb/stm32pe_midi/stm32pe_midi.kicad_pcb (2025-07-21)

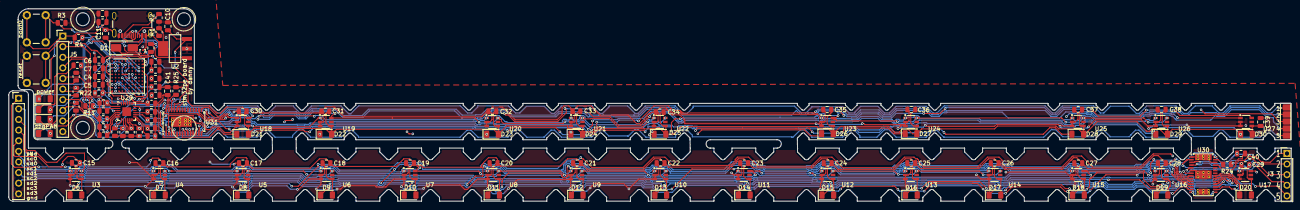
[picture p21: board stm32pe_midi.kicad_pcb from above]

Board: 4 copper layers, 307.0 x 46.1 mm, 135 parts (0 on the bottom side), 83 nets.

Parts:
C1, C2: 2.2μF; C_0805_2012Metric
C3, C5: 4.7μF; C_0805_2012Metric
C4, C6, C7, C9, C12: 100nF; C_0805_2012Metric
C8, C13, C14: 1μF; C_0805_2012Metric
C10: 33μF; C_0805_2012Metric
C11: 0.47μF; C_0805_2012Metric
C15, C16, C17, C18, C19, C20, C21, C22, C23, C24, C25, C26, C27, C28, C29, C30, C31, C32, C33, C34, C35, C36, C37, C38, C39, C40, C41: 0.1μF; C_0805_2012Metric
D1: SS14; D_SMA
D3, D4, D5, D33: LED; LED_1206_3216Metric
D6, D7, D8, D9, D10, D11, D12, D13, D14, D15, D16, D17, D18, D19, D20, D21, D22, D23, D24, D25, D26, D27, D28, D29, D30: LED_Small; LED_1206_3216Metric
J1: USB4105; USB_C_Receptacle_GCT_USB4105-xx-A_16P_TopMnt_Horizontal
J3: Conn_01x05_Pin; PinHeader_1x05_P2.54mm_Vertical
J4: Conn_01x10_Pin; PinHeader_1x10_P2.54mm_Vertical
J5: Conn_01x10_Socket; PinHeader_1x10_P2.54mm_Vertical
J6: Conn_01x05_Pin; custom_pads
R1, R2, R24, R25: 5.1kΩ; R_0805_2012Metric
R3, R4: 10kΩ; R_0805_2012Metric
R5, R6, R7, R27: 330Ω; R_0805_2012Metric
R8, R9, R10, R11, R12, R13, R14, R15, R16, R17, R18, R19, R20, R21, R22, R23: 2.2kΩ; R_0805_2012Metric
SW1, SW2: SW_SPST; SW_PUSH_6mm
U1: STM32H743VIHx; TFBGA-100_8x8mm_Layout10x10_P0.8mm
U2: LM3940IMPX-3.3/NOPB; SOT-223-4_L6.5-W3.5-P2.30-LS7.0-BR
U3, U4, U5, U6, U7, U8, U9, U10, U11, U12, U13, U14, U15, U16, U17, U18, U19, U20, U21, U22, U23, U24, U25, U26, U27: TMAG5273; SOT-23-6_L2.9-W1.6-P0.95-LS2.8-BR
U28: TPD2EUSB30; Texas_DRT-3
U29: TCA9548A; Texas_RGE0024C_VQFN-24-1EP_4x4mm_P0.5mm_EP2.1x2.1mm
U30, U31: TLC5940PWP; HTSSOP-28-1EP_4.4x9.7mm_P0.65mm_EP3.4x9.5mm_Mask2.4x6.17mm_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

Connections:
3v3: C4.2, C5.2, C6.2, C7.2, C10.1, C12.1, C13.1, C15.2, C16.2, C17.2, C18.2, C19.2, C20.2, C21.2, C22.2, C23.2, C24.2, C25.2, C26.2, C27.2, C28.2, C29.2, C30.2, C31.2, C32.2, C33.2, C34.2, C35.2, C36.2, C37.2, C38.2, C39.2, C40.2, C41.2, D3.2 (A), D6.2 (A), D7.2 (A), D8.2 (A), D9.2 (A), D10.2 (A), D11.2 (A), D12.2 (A), D13.2 (A), D14.2 (A), D15.2 (A), D16.2 (A), D17.2 (A), D18.2 (A), D19.2 (A), D20.2 (A), D21.2 (A), D22.2 (A), D23.2 (A), D24.2 (A), D25.2 (A), D26.2 (A), D27.2 (A), D28.2 (A), D29.2 (A), D30.2 (A), J4.1, J5.1, R4.1, R8.2, R9.2, R10.2, R11.2, R12.2, R13.2, R14.2, R15.2, R16.2, R17.2, R18.2, R19.2, R20.2, R21.2, R22.2, R23.2, SW1.2 (B), U1.B2 (VBAT), U1.D2 (VDD), U1.F5 (VDD), U1.F6 (VDD33_USB), U1.K1 (VDD), U2.3 (OUT), U3.4 (VCC), U4.4 (VCC), U5.4 (VCC), U6.4 (VCC), U7.4 (VCC), U8.4 (VCC), U9.4 (VCC), U10.4 (VCC), U11.4 (VCC), U12.4 (VCC), U13.4 (VCC), U14.4 (VCC), U15.4 (VCC), U16.4 (VCC), U17.4 (VCC), U18.4 (VCC), U19.4 (VCC), U20.4 (VCC), U21.4 (VCC), U22.4 (VCC), U23.4 (VCC), U24.4 (VCC), U25.4 (VCC), U26.4 (VCC), U27.4 (VCC), U29.21 (VCC), U30.28 (VCC), U31.28 (VCC)
5v: C11.1, C14.2, U2.1 (IN)
BLANK: J6.2, U1.K2 (PA3), U31.2 (BLANK)
BOOT0: R3.2, SW1.1 (A), U1.D5 (BOOT0)
GND: C1.1, C2.1, C3.1, C4.1, C5.1, C6.1, C7.1, C8.1, C9.1, C10.2, C11.2, C12.2, C13.2, C15.1, C16.1, C17.1, C18.1, C19.1, C20.1, C21.1, C22.1, C23.1, C24.1, C25.1, C26.1, C27.1, C28.1, C29.1, C30.1, C31.1, C32.1, C33.1, C34.1, C35.1, C36.1, C37.1, C38.1, C39.1, C40.1, C41.1, J1.A1 (GND), J1.A12 (GND), J1.B1 (GND), J1.B12 (GND), J1.S1 (SHIELD), J4.10, J5.10, R1.2, R2.1, R3.1, R5.1, R6.1, R7.1, R24.1, R25.1, R27.1, SW2.2 (B), U1.C2 (VSS), U1.E4 (VSS), U1.E5 (VSS), U1.E6 (VSS), U1.G1 (VSSA), U1.J1 (VSS), U2.2 (GND), U2.4 (GND), U3.2 (GND), U3.3 (GND(TEST)), U4.2 (GND), U4.3 (GND(TEST)), U5.2 (GND), U5.3 (GND(TEST)), U6.2 (GND), U6.3 (GND(TEST)), U7.2 (GND), U7.3 (GND(TEST)), U8.2 (GND), U8.3 (GND(TEST)), U9.2 (GND), U9.3 (GND(TEST)), U10.2 (GND), U10.3 (GND(TEST)), U11.2 (GND), U11.3 (GND(TEST)), U12.2 (GND), U12.3 (GND(TEST)), U13.2 (GND), U13.3 (GND(TEST)), U14.2 (GND), U14.3 (GND(TEST)), U15.2 (GND), U15.3 (GND(TEST)), U16.2 (GND), U16.3 (GND(TEST)), U17.2 (GND), U17.3 (GND(TEST)), U18.2 (GND), U18.3 (GND(TEST)), U19.2 (GND), U19.3 (GND(TEST)), U20.2 (GND), U20.3 (GND(TEST)), U21.2 (GND), U21.3 (GND(TEST)), U22.2 (GND), U22.3 (GND(TEST)), U23.2 (GND), U23.3 (GND(TEST)), U24.2 (GND), U24.3 (GND(TEST)), U25.2 (GND), U25.3 (GND(TEST)), U26.2 (GND), U26.3 (GND(TEST)), U27.2 (GND), U27.3 (GND(TEST)), U28.3 (GND), U29.9 (GND), U29.18 (A2), U29.22 (A0), U29.23 (A1), U30.1 (GND), U30.6 (VPRG), U30.26 (DCPRG), U30.29 (PAD), U31.1 (GND), U31.6 (VPRG), U31.26 (DCPRG), U31.29 (PAD)
GSCLK: J6.1, U1.H2 (PA1), U31.25 (GSCLK)
I2C1_SCL: R23.1, U1.B5 (PB6), U29.19 (SCL)
I2C1_SDA: R22.1, U1.A5 (PB7), U29.20 (SDA)
MPRESET: U1.B4 (PB8), U29.24 (~RESET)
NRST: R4.2, SW2.1 (A), U1.E1 (NRST)
unnamed: C1.2, U1.E7 (VCAP)
unnamed: C2.2, U1.F8 (VCAP)
unnamed: D1.2 (A), J1.A4 (VBUS), J1.A9 (VBUS), J1.B4 (VBUS), J1.B9 (VBUS)
unnamed: C14.1, D1.1 (K)
unnamed: D3.1 (K), R5.2
unnamed: D4.1 (K), R6.2
unnamed: D5.1 (K), R7.2
unnamed: D6.1 (K), U30.7 (OUT0)
unnamed: D7.1 (K), U30.8 (OUT1)
unnamed: D8.1 (K), U30.9 (OUT2)
unnamed: D9.1 (K), U30.10 (OUT3)
unnamed: D10.1 (K), U30.11 (OUT4)
unnamed: D11.1 (K), U30.12 (OUT5)
unnamed: D12.1 (K), U30.13 (OUT6)
unnamed: D13.1 (K), U30.14 (OUT7)
unnamed: D14.1 (K), U30.15 (OUT8)
unnamed: D15.1 (K), U30.16 (OUT9)
unnamed: D16.1 (K), U30.17 (OUT10)
unnamed: D17.1 (K), U30.18 (OUT11)
unnamed: D18.1 (K), U30.19 (OUT12)
unnamed: D19.1 (K), U30.20 (OUT13)
unnamed: D20.1 (K), U30.21 (OUT14)
unnamed: D21.1 (K), U31.7 (OUT0)
unnamed: D22.1 (K), U31.8 (OUT1)
unnamed: D23.1 (K), U31.9 (OUT2)
unnamed: D24.1 (K), U31.10 (OUT3)
unnamed: D25.1 (K), U31.11 (OUT4)
unnamed: D26.1 (K), U31.12 (OUT5)
unnamed: D27.1 (K), U31.13 (OUT6)
unnamed: D28.1 (K), U31.14 (OUT7)
unnamed: D29.1 (K), U31.15 (OUT8)
unnamed: D30.1 (K), U31.16 (OUT9)
unnamed: D33.1 (K), R27.2
unnamed: J1.A5 (CC1), R1.1
unnamed: J1.B5 (CC2), R2.2
unnamed: J3.1, U30.25 (GSCLK)
unnamed: J3.2, U30.2 (BLANK)
unnamed: J3.3, U30.3 (XLAT)
unnamed: J3.4, U30.4 (SCLK)
unnamed: J3.5, U30.5 (SIN)
unnamed: J5.2, R9.1, U29.2 (SC0)
unnamed: J5.3, R8.1, U29.1 (SD0)
unnamed: J5.4, R10.1, U29.4 (SC1)
unnamed: J5.5, R11.1, U29.3 (SD1)
unnamed: J5.6, R12.1, U29.6 (SC2)
unnamed: J5.7, R13.1, U29.5 (SD2)
unnamed: J6.5, U31.24 (SOUT)
unnamed: C8.2, C9.2, U1.H1 (VDDA)
unnamed: C3.2, U1.F4 (VDDLDO)
unnamed: R24.2, U30.27 (IREF)
unnamed: R25.2, U31.27 (IREF)
OTG_FS_DM: J1.A7 (D-), J1.B7 (D-), U1.C10 (PA11), U28.2 (D-)
OTG_FS_DP: J1.A6 (D+), J1.B6 (D+), U1.B10 (PA12), U28.1 (D+)
PA8: D33.2 (A), U1.D9 (PA8)
SC0: J4.2, U3.1 (SCL), U4.1 (SCL), U5.1 (SCL), U6.1 (SCL)
SC1: J4.4, U7.1 (SCL), U8.1 (SCL), U9.1 (SCL), U10.1 (SCL)
SC2: J4.6, U11.1 (SCL), U12.1 (SCL), U13.1 (SCL), U14.1 (SCL)
SC3: J4.8, J5.8, R14.1, U15.1 (SCL), U16.1 (SCL), U17.1 (SCL), U18.1 (SCL), U29.8 (SC3)
SC4: R16.1, U19.1 (SCL), U20.1 (SCL), U21.1 (SCL), U22.1 (SCL), U29.11 (SC4)
SC5: R18.1, U23.1 (SCL), U24.1 (SCL), U25.1 (SCL), U26.1 (SCL), U29.13 (SC5)
SC6: R20.1, U27.1 (SCL), U29.15 (SC6)
SCLK: J6.4, U1.H3 (PA5), U31.4 (SCLK)
SD0: J4.3, U3.6 (SDA), U4.6 (SDA), U5.6 (SDA), U6.6 (SDA)
SD1: J4.5, U7.6 (SDA), U8.6 (SDA), U9.6 (SDA), U10.6 (SDA)
SD2: J4.7, U11.6 (SDA), U12.6 (SDA), U13.6 (SDA), U14.6 (SDA)
SD3: J4.9, J5.9, R15.1, U15.6 (SDA), U16.6 (SDA), U17.6 (SDA), U18.6 (SDA), U29.7 (SD3)
SD4: R17.1, U19.6 (SDA), U20.6 (SDA), U21.6 (SDA), U22.6 (SDA), U29.10 (SD4)
SD5: R19.1, U23.6 (SDA), U24.6 (SDA), U25.6 (SDA), U26.6 (SDA), U29.12 (SD5)
SD6: R21.1, U27.6 (SDA), U29.14 (SD6)
SIN: U1.K3 (PA7), U31.5 (SIN)
USART1_RX: D5.2 (A), U1.D10 (PA10)
USART1_TX: D4.2 (A), U1.C9 (PA9)
XLAT: J6.3, U1.J2 (PA2), U31.3 (XLAT)

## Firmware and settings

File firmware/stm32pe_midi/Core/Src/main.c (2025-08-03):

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
/* Includes ------------------------------------------------------------------*/
#include "main.h"

/* USER CODE BEGIN Includes */

//#include "usbd_def.h"
//#include "usbd_cdc_if.h"

#include <stdlib.h>
#include <stdbool.h>
#include <string.h>

#include "tlc5940.h"
#include "i2c-mux.h"
#include "TMAG5273.h"

#include "tusb.h"

#include "helper.h"
#include "mpe.h"

#define DEBUG4_LED_GPIO_Port GPIOA
#define DEBUG4_LED_Pin GPIO_PIN_8

#define DEBUG2_LED_GPIO_Port GPIOA
#define DEBUG2_LED_Pin GPIO_PIN_9

#define DEBUG3_LED_GPIO_Port GPIOA
#define DEBUG3_LED_Pin GPIO_PIN_10

// ==========================================================================================
// the config is below (not really recommended to edit these below unless if yk what you are doing)
// ==========================================================================================

//midi
int start_octave = 4; //midi code shift
int mt_send_black = 40; //midi on threshold
int mt_send_white = 30; //midi on threshold

//mpe
int16_t pitch_mpe_st = 682; //mpe semitone pitch range (682 = 4st, 341 = 2st)
float angle_mpe_padding = 15; //mpe pitch
float angle_mpe_realistic_max = 25; //mpe pitch

float aftertouch_mpe_white_padding = 9; //mpe aftertouch
float aftertouch_mpe_black_padding = 15; //mpe aftertouch

//octave
uint32_t octave_change_mode_time_threshold = 200; //diff change between mode/octive
uint32_t octave_led_flash = 500; //ms between led flash during mode

//led
int startup_cutoff_wait = 100; //led cutoff + cutoff for initial sensor readings saving

//mode
uint32_t octave_mode_hold_down = 1500; //octave mode keys milliseconds to hold down & change
uint32_t mpe_mode_hold_down = 3000; //~ same above but for mpe mode keys

//debug
bool disable_comport = false; //silences comport to possibly make processing faster?

// ==========================================================================================
// the config is above
// ==========================================================================================

//all data below is in order of b, c, c#, d, d#, e, etc..
//uint16_t light_key_arr[25];

bool key_activated[25]; //midi on/off
uint8_t key_note_active[25]; //midi on/off safety

float key_raw_initial[25]; //midi velocity
float key_raw_angle_initial[25]; //mpe pitch

float key_tick_start[25]; //midi velocity

float key_low_cutoff[25]; //leds

float key_off_cutoff[25]; //midi off

uint8_t midi_key_arr[25]; //midi codes

TMAG5273_Handle_t tmag_handles[25]; //tmag obj handles

uint8_t tmag_addr_arr[25] = { 0x10, 0x11, 0x12, 0x13, 0x14, 0x15, 0x16,
		0x17, 0x18, 0x19, 0x1A, 0x1B, 0x1C, 0x1D, 0x1E, 0x1F, 0x20, 0x21, 0x22,
		0x23,
		0x24, 0x25, 0x26, 0x27, 0x28 }; //tmag addresses

bool is_black_key[25] = { false, false, true, false, true, false, false, true,
		false, true, false, true, false, false, true, false, true, false, false,
		true, false, true, false, true, false };

uint32_t octave_held_time = -1; //octave mode change
uint32_t octave_mode_time_elapsed = 0; //octave led
uint32_t octave_mode_time2_elapsed = -1; //mode change safety

bool octave_change_mode = false; //mode on/off
bool prevent_rapid_fire = false; //can change octave

bool mpe_midi_mode = true; //mpe mode change
uint32_t mpe_held_time = -1; //time saving

/* USER CODE END Includes */


I2C_HandleTypeDef hi2c1;

SPI_HandleTypeDef hspi1;

TIM_HandleTypeDef htim2;

PCD_HandleTypeDef hpcd_USB_OTG_FS;

/* USER CODE BEGIN PV */

//TODO remove?

/* USER CODE END PV */

void SystemClock_Config(void);
static void MPU_Config(void);
static void MX_GPIO_Init(void);
static void MX_TIM2_Init(void);
static void MX_SPI1_Init(void);
static void MX_I2C1_Init(void);
static void MX_USB_OTG_FS_PCD_Init(void);
/* USER CODE BEGIN 0 */

i2c_mux_t tca_mux = { .hi2c = &hi2c1,     // Using I2C1 on PB6 (SCL) / PB7 (SDA)
		.rst_port = GPIOB,          // Reset pin is PB7
		.rst_pin = GPIO_PIN_8,      // Use correct GPIO pin number
		.addr_offset = 0            // 0 if all A0/A1/A2 pins are GND
		};

int _write(int file, char *ptr, int len) {
	(void) file;

	if (disable_comport) {
		return 0;
	}

	if (!tud_cdc_connected()) {
		return 0;
	}

	int remaining = len;
	uint32_t start = HAL_GetTick();
	while (remaining > 0) {
		uint32_t n = tud_cdc_write(ptr, remaining);
		tud_cdc_write_flush(); // send data to host
		ptr += n;
		remaining -= n;

		// Allow TinyUSB to process USB events
		tud_task();

		// Timeout after 100ms to avoid deadlock
		if ((HAL_GetTick() - start) > 100) {
			break;
		}
	}

	return len;
}

/* USER CODE END 0 */

/**
  * @brief  The application entry point.
  * @retval int
  */
int main(void)
{

  /* MPU Configuration--------------------------------------------------------*/
  MPU_Config();

  /* MCU Configuration--------------------------------------------------------*/

  /* Reset of all peripherals, Initializes the Flash interface and the Systick. */
  HAL_Init();

  /* Configure the system clock */
  SystemClock_Config();

  /* Initialize all configured peripherals */
  MX_GPIO_Init();
  MX_TIM2_Init();
  MX_SPI1_Init();
  MX_I2C1_Init();
  MX_USB_OTG_FS_PCD_Init();
  /* USER CODE BEGIN 2 */

	// start the timer for the led mux
	HAL_TIM_PWM_Start(&htim2, TIM_CHANNEL_2);

	// set mp-reset on the i2c mux to be high as it is active-low reset input
	HAL_GPIO_WritePin(GPIOB, GPIO_PIN_8, GPIO_PIN_SET);

	// disable all i2c channels for a clean slate bruh
	if (i2c_mux_reset(&tca_mux) != 0) {
		// Handle error, e.g., blink LED or halt
		HAL_GPIO_WritePin(DEBUG2_LED_GPIO_Port, DEBUG2_LED_Pin, GPIO_PIN_SET);
	}

	//on each channel, there are four i2c sensors connected with unique addresses in that channel only
	//the address has to be rewritten for all the sensors to then combine all channels pull data easier

	//sc0
	i2c_mux_select(&tca_mux, 0);

	tmag_handles[0] = TMAG5273_CreateHandle(&hi2c1, 0x35);
	TMAG5273_Init(&tmag_handles[0]);
	TMAG5273_RewriteI2CAddress(&tmag_handles[0], tmag_addr_arr[0]);

	tmag_handles[1] = TMAG5273_CreateHandle(&hi2c1, 0x22);
	TMAG5273_Init(&tmag_handles[1]);
	TMAG5273_RewriteI2CAddress(&tmag_handles[1], tmag_addr_arr[1]);

	tmag_handles[3] = TMAG5273_CreateHandle(&hi2c1, 0x78);
	TMAG5273_Init(&tmag_handles[3]);
	TMAG5273_RewriteI2CAddress(&tmag_handles[3], tmag_addr_arr[3]);

	tmag_handles[5] = TMAG5273_CreateHandle(&hi2c1, 0x44);
	TMAG5273_Init(&tmag_handles[5]);
	TMAG5273_RewriteI2CAddress(&tmag_handles[5], tmag_addr_arr[5]);

	
	//sc1
	i2c_mux_select(&tca_mux, 1);

	tmag_handles[6] = TMAG5273_CreateHandle(&hi2c1, 0x35);
	TMAG5273_Init(&tmag_handles[6]);
	TMAG5273_RewriteI2CAddress(&tmag_handles[6], tmag_addr_arr[6]);

	tmag_handles[8] = TMAG5273_CreateHandle(&hi2c1, 0x22);
	TMAG5273_Init(&tmag_handles[8]);
	TMAG5273_RewriteI2CAddress(&tmag_handles[8], tmag_addr_arr[8]);

	tmag_handles[10] = TMAG5273_CreateHandle(&hi2c1, 0x78);
	TMAG5273_Init(&tmag_handles[10]);
	TMAG5273_RewriteI2CAddress(&tmag_handles[10], tmag_addr_arr[10]);

	tmag_handles[12] = TMAG5273_CreateHandle(&hi2c1, 0x44);
	TMAG5273_Init(&tmag_handles[12]);
	TMAG5273_RewriteI2CAddress(&tmag_handles[12], tmag_addr_arr[12]);


	//sc2
	i2c_mux_select(&tca_mux, 2);

	tmag_handles[13] = TMAG5273_CreateHandle(&hi2c1, 0x35);
	TMAG5273_Init(&tmag_handles[13]);
	TMAG5273_RewriteI2CAddress(&tmag_handles[13], tmag_addr_arr[13]);

	tmag_handles[15] = TMAG5273_CreateHandle(&hi2c1, 0x22);
	TMAG5273_Init(&tmag_handles[15]);
	TMAG5273_RewriteI2CAddress(&tmag_handles[15], tmag_addr_arr[15]);

	tmag_handles[17] = TMAG5273_CreateHandle(&hi2c1, 0x78);
	TMAG5273_Init(&tmag_handles[17]);
	TMAG5273_RewriteI2CAddress(&tmag_handles[17], tmag_addr_arr[17]);

	tmag_handles[18] = TMAG5273_CreateHandle(&hi2c1, 0x44);
	TMAG5273_Init(&tmag_handles[18]);
	TMAG5273_RewriteI2CAddress(&tmag_handles[18], tmag_addr_arr[18]);


	//sc3
	i2c_mux_select(&tca_mux, 3);

	tmag_handles[20] = TMAG5273_CreateHandle(&hi2c1, 0x35);
	TMAG5273_Init(&tmag_handles[20]);
	TMAG5273_RewriteI2CAddress(&tmag_handles[20], tmag_addr_arr[20]);

	tmag_handles[22] = TMAG5273_CreateHandle(&hi2c1, 0x22);
	TMAG5273_Init(&tmag_handles[22]);
	TMAG5273_RewriteI2CAddress(&tmag_handles[22], tmag_addr_arr[22]);

	tmag_handles[24] = TMAG5273_CreateHandle(&hi2c1, 0x78);
	TMAG5273_Init(&tmag_handles[24]);
	TMAG5273_RewriteI2CAddress(&tmag_handles[24], tmag_addr_arr[24]);

	tmag_handles[2] = TMAG5273_CreateHandle(&hi2c1, 0x44);
	TMAG5273_Init(&tmag_handles[2]);
	TMAG5273_RewriteI2CAddress(&tmag_handles[2], tmag_addr_arr[2]);


	//sc4
	i2c_mux_select(&tca_mux, 4);

	tmag_handles[4] = TMAG5273_CreateHandle(&hi2c1, 0x35);
	TMAG5273_Init(&tmag_handles[4]);
	TMAG5273_RewriteI2CAddress(&tmag_handles[4], tmag_addr_arr[4]);

	tmag_handles[7] = TMAG5273_CreateHandle(&hi2c1, 0x22);
	TMAG5273_Init(&tmag_handles[7]);
	TMAG5273_RewriteI2CAddress(&tmag_handles[7], tmag_addr_arr[7]);

	tmag_handles[9] = TMAG5273_CreateHandle(&hi2c1, 0x78);
	TMAG5273_Init(&tmag_handles[9]);
	TMAG5273_RewriteI2CAddress(&tmag_handles[9], tmag_addr_arr[9]);

	tmag_handles[11] = TMAG5273_CreateHandle(&hi2c1, 0x44);
	TMAG5273_Init(&tmag_handles[11]);
	TMAG5273_RewriteI2CAddress(&tmag_handles[11], tmag_addr_arr[11]);


	//sc5
	i2c_mux_select(&tca_mux, 5);

	tmag_handles[14] = TMAG5273_CreateHandle(&hi2c1, 0x35);
	TMAG5273_Init(&tmag_handles[14]);
	TMAG5273_RewriteI2CAddress(&tmag_handles[14], tmag_addr_arr[14]);

	tmag_handles[16] = TMAG5273_CreateHandle(&hi2c1, 0x22);
	TMAG5273_Init(&tmag_handles[16]);
	TMAG5273_RewriteI2CAddress(&tmag_handles[16], tmag_addr_arr[16]);

	tmag_handles[19] = TMAG5273_CreateHandle(&hi2c1, 0x78);
	TMAG5273_Init(&tmag_handles[19]);
	TMAG5273_RewriteI2CAddress(&tmag_handles[19], tmag_addr_arr[19]);

	tmag_handles[21] = TMAG5273_CreateHandle(&hi2c1, 0x44);
	TMAG5273_Init(&tmag_handles[21]);
	TMAG5273_RewriteI2CAddress(&tmag_handles[21], tmag_addr_arr[21]);


	//sc6
	i2c_mux_select(&tca_mux, 6);

	tmag_handles[23] = TMAG5273_CreateHandle(&hi2c1, 0x35);
	TMAG5273_Init(&tmag_handles[23]);
	TMAG5273_RewriteI2CAddress(&tmag_handles[23], tmag_addr_arr[23]);



	// enable sc0–sc6, disable sc7
	i2c_mux_select_multi(&tca_mux, 0x7F);




	// fill midi array
	fill_midi_key_arr(midi_key_arr, 25, start_octave);

	// init high/low cutoffs & other stuff
	for (int i = 0; i < 25; i++) {
		key_low_cutoff[i] = -1.0f;
		key_tick_start[i] = 0;
		key_raw_angle_initial[i] = -1;
	}

	// for if the user changed the default midi mpe mode
	if (mpe_midi_mode) {
		HAL_GPIO_WritePin(DEBUG3_LED_GPIO_Port, DEBUG3_LED_Pin, GPIO_PIN_RESET);
	} else {
		HAL_GPIO_WritePin(DEBUG3_LED_GPIO_Port, DEBUG3_LED_Pin, GPIO_PIN_SET);
	}

	// init device stack for tiny usb!!!
	tusb_init(BOARD_DEVICE_RHPORT_NUM, NULL);

  /* USER CODE END 2 */

  /* Infinite loop */
  /* USER CODE BEGIN WHILE */
  while (1)
  {
    /* USER CODE END WHILE */

    /* USER CODE BEGIN 3 */

		tud_task();

		//dont allow cutoffs to be set until a solid line of sensor values are being read good
		static uint32_t startup_tick = 0;
		if (startup_tick == 0) {
			startup_tick = HAL_GetTick();
		}
		uint8_t allow_cutoff_set = (HAL_GetTick() - startup_tick
				> startup_cutoff_wait);
		// ^ this time is how long the user can not touch the keys after being plugged in

		//for each 25 keys
		for (int d = 0; d < 25; d++) {

			// read address register to see if address is actually rewritten
			//TODO remove in next code cleanup
			uint8_t addr_reg = 0;
			if (TMAG5273_ReadRegister(&tmag_handles[d], 0x0C, 1, &addr_reg)
					== 0) {
				//printf("I2C address register: 0x%02X\r\n", addr_reg);
			} else {
				printf(
						"Sensor Index = %d, Failed to read i2c register data\r\n",
						d);
			};

			// reading rotation from sensor
			TMAG5273_Axis_t mag;
			TMAG5273_Angle_t angle;
			uint8_t ret = -1;

			// reading sensor magnet pos. to output led/etc.
			ret = TMAG5273_ReadMagneticField(&tmag_handles[d], &mag);
			if (ret == 0) {
				//printf("Bx = %.3f mT, By = %.3f mT, Bz = %.3f mT\r\n", mag.Bx, mag.By, mag.Bz);
				//printf("Return value: %u\r\n", ret);

				uint16_t bz_u16 = 0;

				//use the key_low_cutoff nan to set an initial cutoff for later calculations
				if (key_low_cutoff[d] < 0 && allow_cutoff_set) {
					if (mag.Bz > 9) {
						key_low_cutoff[d] = mag.Bz - 9;
					} else {
						key_low_cutoff[d] = 0;
					}

					key_off_cutoff[d] = mag.Bz + 5; //add a padding of 5

					key_raw_initial[d] = mag.Bz;

					//key_raw_angle_initial[d] = angle.angle -- moved to key on for reasons explained
				} else {
					//normalize mag.Bz around ~9
					bz_u16 = map_float_to_int16(mag.Bz - key_low_cutoff[d],
							10.0f, 80.0f, 0, 3000);
				}

				TLC5940_SetMappedByKeyLED(d, bz_u16);
				TLC5940_Update();
			} else {
				printf(
						"I2C Address = 0x%02X, Sensor Index = %d, ReadMagneticField failed code = %d\r\n",
						addr_reg, d, ret);
			}

			ret = TMAG5273_ReadAngle(&tmag_handles[d], &angle);
			if (ret == 0) {
				//printf("Angle: %.2f deg, Magnitude: %.2f\r\n", angle.angle, angle.magnitude);
			} else {
				printf("Sensor Index = %d, Failed angle read, code: %d\r\n", d,
						ret);
			}

			//mpe midi mode change
			if (key_activated[1] && key_activated[22]) {
				if (mpe_held_time == -1) {
					//set the first time
					mpe_held_time = HAL_GetTick();
				} else if ((HAL_GetTick() - mpe_held_time) > mpe_mode_hold_down
						&& mpe_held_time != -1) {
					//count down the time until its more than 3 seconds held
					mpe_midi_mode = !mpe_midi_mode;

					if (mpe_midi_mode) {
						HAL_GPIO_WritePin(DEBUG3_LED_GPIO_Port, DEBUG3_LED_Pin,
								GPIO_PIN_RESET);
					} else {
						HAL_GPIO_WritePin(DEBUG3_LED_GPIO_Port, DEBUG3_LED_Pin,
								GPIO_PIN_SET);
					}

					//prevent rapid fire of changing modes
					mpe_held_time = -1;
				}
			} else if (!key_activated[1] && !key_activated[22]) {
				//reset time if both keys are unactivated
				mpe_held_time = -1;
			}

			//octave change
			if (key_activated[0] && key_activated[24]) {
				if (octave_held_time == -1) {
					//set the first time
					octave_held_time = HAL_GetTick();
				} else if ((HAL_GetTick() - octave_held_time)
						> octave_mode_hold_down
						&& octave_held_time != -1) {
					//count down the time until its more than 3 seconds held
					octave_change_mode = !octave_change_mode;

					if (octave_change_mode) {
						octave_mode_time_elapsed = HAL_GetTick();
					} else {
						HAL_GPIO_WritePin(DEBUG4_LED_GPIO_Port, DEBUG4_LED_Pin,
								GPIO_PIN_RESET);
					}

					//prevent rapid fire of changing modes
					octave_held_time = -1;
				}
			} else if (!key_activated[0] && !key_activated[24]) {
				//reset time if both keys are unactivated
				octave_held_time = -1;
			}

			//turn status led on to indicate octave change mode
			if (octave_change_mode
					&& (HAL_GetTick() - octave_mode_time_elapsed)
							> octave_led_flash) {
				HAL_GPIO_TogglePin(DEBUG4_LED_GPIO_Port, DEBUG4_LED_Pin);
				octave_mode_time_elapsed = HAL_GetTick();
			}

			//octave down
			if (d == 0 && mag.Bz > mt_send_white && start_octave >= 0
					&& !prevent_rapid_fire && octave_change_mode) {
				if (octave_mode_time2_elapsed == -1) {
					octave_mode_time2_elapsed = HAL_GetTick();
				} else if (key_activated[0] && key_activated[24]) {
					//catch if user is trying to exit octave mode instead of changing it
					octave_mode_time2_elapsed = -1;

				} else if ((HAL_GetTick() - octave_mode_time2_elapsed)
						> octave_change_mode_time_threshold) {
					start_octave--;
					fill_midi_key_arr(midi_key_arr, 25, start_octave);
					prevent_rapid_fire = true;
					octave_mode_time2_elapsed = -1;
				}
			}

			//octave up
			if (d == 24 && mag.Bz > mt_send_white && start_octave <= 9
					&& !prevent_rapid_fire && octave_change_mode) {
				if (octave_mode_time2_elapsed == -1) {
					octave_mode_time2_elapsed = HAL_GetTick();
				} else if (key_activated[0] && key_activated[24]) {
					//catch if user is trying to exit octave mode instead of changing it
					octave_mode_time2_elapsed = -1;

				} else if ((HAL_GetTick() - octave_mode_time2_elapsed)
						> octave_change_mode_time_threshold) {
					start_octave++;
					fill_midi_key_arr(midi_key_arr, 25, start_octave);
					prevent_rapid_fire = true;
					octave_mode_time2_elapsed = -1;
				}
			}

			//TODO remove next code cleanup
			//printf("Bz = %.3f mT, Angle: %.2f deg, Change: %.2f, Max: %.2f\r\n", mag.Bz, angle.angle, current_change, key_dist_max[d]);

			//start time for measuring velocity
			if (mag.Bz > key_raw_initial[d] + 1.5 && key_tick_start[d] == 0) {
				key_tick_start[d] = HAL_GetTick();
			} else if (mag.Bz < key_raw_initial[d] + 0.8
					&& key_tick_start[d] != 0) {
				//safety measure to stop measuring tick start as user has started measurement but did not trigger a key press
				key_tick_start[d] = 0;
			}

			//use a specific mt send as the black keys have a shorter distance compared to white keys
			int mt_send = is_black_key[d] ? mt_send_black : mt_send_white;

			//turn on key
			if (mag.Bz > mt_send && !key_activated[d]) {
				uint8_t measured_velocity = map_velocity_log(
						HAL_GetTick() - key_tick_start[d]);
				
				if (mpe_midi_mode) {
					MPE_Send_Note_On(midi_key_arr[d], measured_velocity);
				} else {
					uint8_t note_on[3] = { 0x90 | 0, midi_key_arr[d],
							measured_velocity };

					tud_midi_stream_write(0, note_on, 3);
				}

				printf(
						"%d, midi = on, code = %d, velocity = %d\r\n", d,
						midi_key_arr[d], measured_velocity);
				
				key_activated[d] = true;
				key_note_active[d] = midi_key_arr[d];

				//also set the raw initial angle here...
				//some downsides of this is that the user has to press the key perfectly/mostly flat at startup or else the pitch will be offset
				//though, this does solve the issue of the sensor changing the angle when the key is normally actuated for some reason
				if (key_raw_angle_initial[d] == -1) {
					key_raw_angle_initial[d] = angle.angle;
					printf("%d, raw angle init = %0.2f\r\n", d,
							key_raw_angle_initial[d]);
				}
			}

			//turn off key
			if (mag.Bz < key_off_cutoff[d] && key_activated[d]) {
				if (mpe_midi_mode) {
					MPE_Send_Note_Off(key_note_active[d]);
				} else {
					uint8_t note_off[3] = { 0x80 | 0, key_note_active[d], 0 };

					tud_midi_stream_write(0, note_off, 3);
				}

				printf("%d, midi = off, code = %d\r\n", d, key_note_active[d]);

				key_activated[d] = false;
				key_note_active[d] = 0;

				//reset velocity measurement
				key_tick_start[d] = 0;

				prevent_rapid_fire = false;
			}

			//pitch change per key
			if (key_activated[d] && mpe_midi_mode) {
				// black key bias - 40max, 44, 91-94-100mid, 134, 150max
				// white key bias - 20max, 30, 82-84-86mid, 130, 140max
				// +-20 from origin angle, +-5/3 as rest from origin angle
				int16_t shift = 0;

				if (angle.angle
						> (key_raw_angle_initial[d] + angle_mpe_padding)) { //up
					//min - the min includes the key's resting angle and the padding before pitch change gets triggered
					//max - includes the above + the realistic max angle/roll for each key
					shift = map_float_to_int16(angle.angle,
							(key_raw_angle_initial[d] + angle_mpe_padding),
							(key_raw_angle_initial[d] + angle_mpe_padding
									+ angle_mpe_realistic_max), 0,
							pitch_mpe_st);
				} else if (angle.angle
						< (key_raw_angle_initial[d] - angle_mpe_padding)) { //down
					//same min/max for pitching up, but negative
					shift = map_float_to_int16(angle.angle,
							(key_raw_angle_initial[d] - angle_mpe_padding
									- angle_mpe_realistic_max),
							(key_raw_angle_initial[d] - angle_mpe_padding),
							-pitch_mpe_st, 0);
				}

				MPE_Send_Pitch_Bend(midi_key_arr[d], shift);
			}

			int aftertouch_mpe_padding =
					is_black_key[d] ?
							aftertouch_mpe_black_padding :
							aftertouch_mpe_white_padding;
			
			//aftertouch per key
			if (mag.Bz > (mt_send + aftertouch_mpe_padding)
					&& key_activated[d]
					&& mpe_midi_mode) {
				uint8_t pressure = 0;

				pressure = map_float_to_uint8(mag.Bz,
						(mt_send + aftertouch_mpe_padding), 78, 0, 127);

				MPE_Send_Aftertouch(midi_key_arr[d], pressure);
			}
		}

  }
  /* USER CODE END 3 */
}

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
 /* MPU Configuration */

void MPU_Config(void)
{
  MPU_Region_InitTypeDef MPU_InitStruct = {0};

  /* Disables the MPU */
  HAL_MPU_Disable();

  /** Initializes and configures the Region and the memory to be protected
  */
  MPU_InitStruct.Enable = MPU_REGION_ENABLE;
  MPU_InitStruct.Number = MPU_REGION_NUMBER0;
  MPU_InitStruct.BaseAddress = 0x0;
  MPU_InitStruct.Size = MPU_REGION_SIZE_4GB;
  MPU_InitStruct.SubRegionDisable = 0x87;
  MPU_InitStruct.TypeExtField = MPU_TEX_LEVEL0;
  MPU_InitStruct.AccessPermission = MPU_REGION_NO_ACCESS;
  MPU_InitStruct.DisableExec = MPU_INSTRUCTION_ACCESS_DISABLE;
  MPU_InitStruct.IsShareable = MPU_ACCESS_SHAREABLE;
  MPU_InitStruct.IsCacheable = MPU_ACCESS_NOT_CACHEABLE;
  MPU_InitStruct.IsBufferable = MPU_ACCESS_NOT_BUFFERABLE;

  HAL_MPU_ConfigRegion(&MPU_InitStruct);
  /* Enables the MPU */
  HAL_MPU_Enable(MPU_PRIVILEGED_DEFAULT);

}

/**
  * @brief  This function is executed in case of error occurrence.
  * @retval None
  */
void Error_Handler(void)
{
  /* USER CODE BEGIN Error_Handler_Debug */
	/* User can add his own implementation to report the HAL error return state */
	__disable_irq();
	while (1) {

	}
  /* USER CODE END Error_Handler_Debug */
}
#ifdef USE_FULL_ASSERT
/**
  * @brief  Reports the name of the source file and the source line number
  *         where the assert_param error has occurred.
  * @param  file: pointer to the source file name
  * @param  line: assert_param error line source number
  * @retval None
  */
void assert_failed(uint8_t *file, uint32_t line)
{
  /* USER CODE BEGIN 6 */
  /* User can add his own implementation to report the file name and line number,
     ex: printf("Wrong parameters value: file %s on line %d\r\n", file, line) */
  /* USER CODE END 6 */
}
#endif /* USE_FULL_ASSERT */

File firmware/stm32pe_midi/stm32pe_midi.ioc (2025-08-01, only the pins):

Mcu.UserName=STM32H743VIHx
PA1.Signal=S_TIM2_CH2
PA10.Signal=GPIO_Output
PA11.Signal=USB_OTG_FS_DM
PA12.Signal=USB_OTG_FS_DP
PA2.Signal=GPIO_Output
PA3.Signal=GPIO_Output
PA5.Signal=SPI1_SCK
PA7.Signal=SPI1_MOSI
PA8.Signal=GPIO_Output
PA9.Signal=GPIO_Output
PB6.Signal=I2C1_SCL
PB7.Signal=I2C1_SDA
PB8.Signal=GPIO_Output

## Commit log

2025-06-11 add cad
    [v1.f3d, v1.stl, v2.f3d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]
2025-06-13 add cad files
    [12.stl, 13.stl, 14.stl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]
2025-06-25 add everything
    [SOT-223-4P_L6.5-W3.5-H1.6-LS7.0-P2.30.step, SOT-23-6_L2.9-W1.6-H1.5-LS2.8-P0.95.step, audio.kicad_sch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]
2025-06-25 add pcb 3d models
2025-06-29 add jlcpcb extra info
    [bom.csv, bom.xls]
2025-07-21 add wip firmware
    [bom.csv, designators.csv, positions.csv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]
2025-07-22 init my TCA9548A i2c mux
2025-07-28 tmag sensor works finally
2025-07-30 add velocity calculations
2025-07-30 stl and images
    [Case L.stl, Case R.stl, hc_flexure_key_magdim_good.stl]
2025-08-01 all keys/sensors implemented
2025-08-01 velocity fully works
2025-08-03 add mpe pitch + aftertouch + tuning

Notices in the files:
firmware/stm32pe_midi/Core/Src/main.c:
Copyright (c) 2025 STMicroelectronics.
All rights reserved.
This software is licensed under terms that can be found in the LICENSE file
